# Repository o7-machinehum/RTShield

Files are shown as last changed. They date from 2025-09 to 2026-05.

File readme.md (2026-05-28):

# RPI RTShield
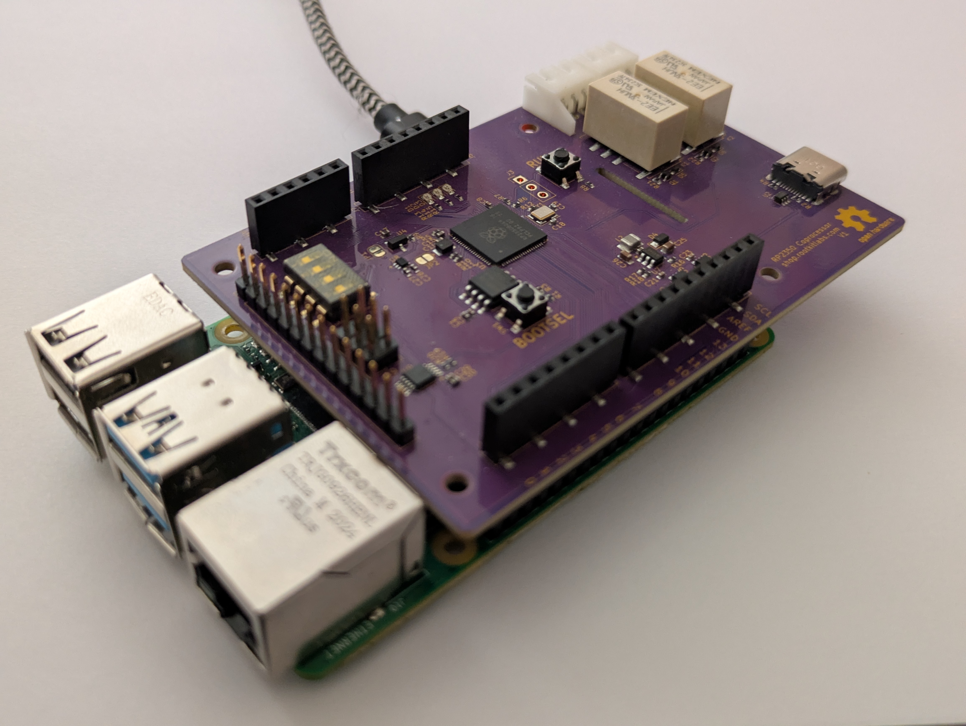
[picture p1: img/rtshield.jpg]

The RTSheild is a Raspberry PI hat containing an MCU to serve as a "realtime" companion. The PI is connected to the RP2350 over a UART link, and all sensors are wired into the RP2350 itself. The RP2350 is connected to Arduino compatible headers

## IOs
- 4x Analog output (0-3.3V, 12bit)
- 8x Analog input (0-3.3V, 12bit)
- IO's (3.3V)
- 2x Relays, for dry contacts
- Switches, for config
- LEDs

## Installing
``` bash
git clone https://github.com/o7-machinehum/RTShield
cd RTShield
git submodule update --init --recursive

sudo apt update
sudo apt install -y build-essential cmake ninja-build gcc-arm-none-eabi \
    libnewlib-arm-none-eabi python3-dev python3-pybind11 openocd

sudo raspi-config nonint do_serial_cons 1
sudo raspi-config nonint do_serial_hw 0
sudo usermod -aG dialout "$USER"

make
make flash # This flashes the RP2350

make install

# Reboot once so the serial-console setting and dialout group membership apply.
sudo reboot
```

## Running
The Python API talks to the shield over `/dev/serial0`:

``` python
import rtshield

s = rtshield.Shield("/dev/serial0")
print(s.read_analog_raw(0))
s.write_analog_voltage(0, 1.25)
s.write_digital(2, True)
s.set_led(0, True)
s.set_relay(0, True)
print(s.read_switch(0))
```

## MCU <-> RPI Coms
It's worth mentioning the UART between the MCU and the RPI isn't done very nicely right now. This is to keep things simple. I will eventually do a proper cobs encoding scheme and make things nicer.

## License
The project is licensed under the Creative Commons (4.0 International License) Attribution—Noncommercial—Share Alike license. This allows sharing and adapting material for non-commercial purposes, provided credit is given to the creator and adaptations are shared under the same terms. The material can be used in any format with necessary technical modifications, but no warranties are provided. The license prohibits imposing additional restrictions and ensures the rights are irrevocable as long as the terms are followed.

Basically... If you make boards for yourself: great, make boards for your friends: great, but **please do not sell hundreds on them on Aliexpress**.

Files in `docs/` 3rd party reference material are not covered by this licence.

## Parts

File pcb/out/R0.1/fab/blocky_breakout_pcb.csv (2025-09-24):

Reference | Value | Footprint | MPN
R7 | 0R | Resistor_SMD:R_0402_1005Metric | RC0402FR-070RL
C18,C19 | 15pF | Capacitor_SMD:C_0402_1005Metric | GJM1555C1H150GB01D
C2,C3,C4,C5,C7,C8,C9,C10,C11,C12,C13,C20,C21,C22,C23,C29 | 100nF | Capacitor_SMD:C_0402_1005Metric | CL05B104KP5NNNC
C1,C24,C27,C28 | 1uF | Capacitor_SMD:C_0402_1005Metric | JMK105BJ105KV-F
L2 | 2.2uH | Inductor_SMD:L_1008_2520Metric | DFE252012P-2R2M=P2
C6,C14,C15,C16,C17,C30 | 4.7uF | Capacitor_SMD:C_0402_1005Metric | JMK105BBJ475MV-F
C25,C26 | 10uF | Capacitor_SMD:C_0603_1608Metric | GRM188R61E106KA73J
R5,R10,R11 | 27R | Resistor_SMD:R_0402_1005Metric | RC0402FR-1327RL
R3,R6,R8,R9,R12,R13,R14,R15,R19,R20,R21,R22 | 1k | Resistor_SMD:R_0402_1005Metric | RC0402FR-131KL
R2,R4 | 5.6k | Resistor_SMD:R_0402_1005Metric | RC0402FR-135K6L
R1 | 10k | Resistor_SMD:R_0402_1005Metric | RC0402FR-1310KL
R18 | 15.8k | Resistor_SMD:R_0402_1005Metric | RC0402FR-1315K8L
R17 | 49.9k | Resistor_SMD:R_0402_1005Metric | RC0402FR-1349K9L
R16 | 100k | Resistor_SMD:R_0402_1005Metric | RC0402FR-13100KL
Y1 | 12Mhz | X_Abracon:Crystal_SMD_Abracon_ABM8-272-T3-4Pin_3.2x2.5mm | ABM8-272-T3
L1 | 3u3 | L_Abracon:AOTA-B201610S3R3-101-T | AOTA-B201610S3R3-101-T
U7 | AOZ1280CI | Package_TO_SOT_SMD:SOT-23-6 | AOZ1280CI
D5,D6 | BAT54XV2T1G | Diode_SMD:D_SOD-523 | BAT54XV2T1G
J10,J11 | Conn_01x03_Pin | Connector_JST:JST_XH_S3B-XH-A-1_1x03_P2.50mm_Horizontal | S3B-XH-A-1
J7 | Conn_01x06_Pin | Connector_PinSocket_2.54mm:PinSocket_1x06_P2.54mm_Vertical_SMD_Pin1Left | NPTC061KFXC-RC
J5,J8 | Conn_01x08_Pin | Connector_PinSocket_2.54mm:PinSocket_1x08_P2.54mm_Vertical_SMD_Pin1Left | NPTC081KFXC-RC
J6 | Conn_01x10_Pin | Connector_PinSocket_2.54mm:PinSocket_1x10_P2.54mm_Vertical_SMD_Pin1Left | NPTC101KFXC-RC
J2 | Conn_01x14_Pin | Connector_PinHeader_2.54mm:PinHeader_1x14_P2.54mm_Vertical | 77311-101-14LF
J9 | Conn_02x03_Odd_Even | Connector_PinHeader_2.54mm:PinHeader_2x03_P2.54mm_Vertical | 67997-206HLF
Q1,Q2 | DMG1012TQ-7 | Package_TO_SOT_SMD:SOT-523 | DMG1012TQ-7
K1,K4 | EE2-3NUH | Relay_SMD:Relay_DPDT_Kemet_EE2_NUH
D2 | Green | LED_SMD:LED_0603_1608Metric | LTST-C190GKT
U5,U6 | LM66100DCK | Package_TO_SOT_SMD:SOT-363_SC-70-6 | LM66100DCKR
U4 | LM4040C33FTA | Package_TO_SOT_SMD:SOT-23 | LM4040C33FTA
U9 | MCP4728 | Package_SO:MSOP-10_3x3mm_P0.5mm | MCP4728T-E/UN
D4 | MSS2P3 | Diode_SMD:D_MicroSMP_AK | MSS2P3-M3/89A
U2 | NUP2202 | Package_TO_SOT_SMD:SOT-363_SC-70-6 | NUP2202W1T2G
J4 | Raspberry_Pi_4 | Connector_PinSocket_2.54mm:PinSocket_2x20_P2.54mm_Vertical_SMD | NPTC202KFMS-RC
D1 | Red | LED_SMD:LED_0603_1608Metric | LTST-C190KRKT
U3 | RP2350 | Package_DFN_QFN:QFN-80-1EP_10x10mm_P0.4mm_EP3.4x3.4mm | RP2350B
SW3 | SW_DIP_x04 | Button_Switch_SMD:SW_DIP_SPSTx04_Slide_Omron_A6S-410x_W8.9mm_P2.54mm | A6S-4102-PH
SW1,SW2 | SW_Push | Button_Switch_SMD:SW_SPST_PTS647_Sx38 | PTS647SK38SMTR2 LFS
U8 | TCR2EE11 | Package_TO_SOT_SMD:SOT-553 | TCR2EE11,LM(CT
J1 | USB_C_Receptacle_USB2.0_16P | Connector_USB:USB_C_Receptacle_GCT_USB4105-xx-A_16P_TopMnt_Horizontal | USB4105-GF-A-120
U1 | W25Q32JVSS | Package_SO:SOIC-8_5.3x5.3mm_P1.27mm | W25Q32JVSSIQ
D3 | Yellow | LED_SMD:LED_0603_1608Metric | LTST-C190KSKT

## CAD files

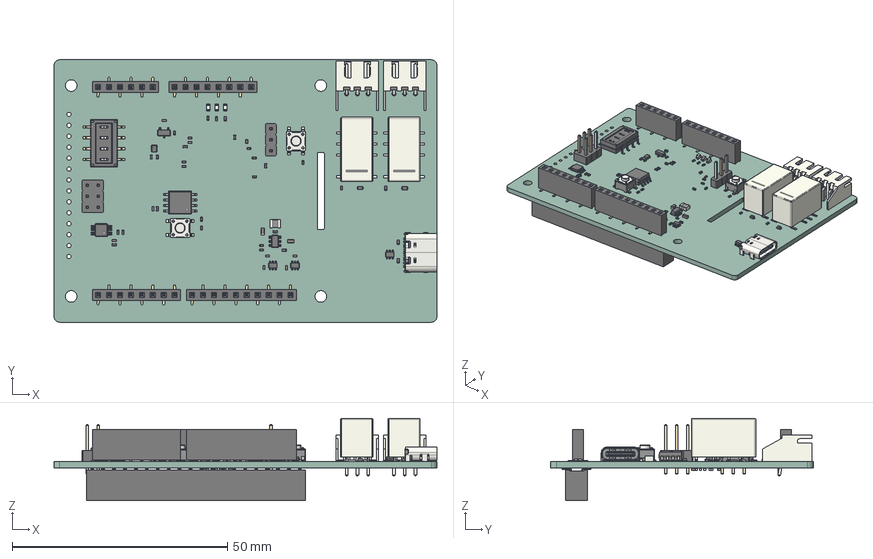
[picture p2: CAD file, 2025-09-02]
pcb/out/R0.1/blocky_breakout_pcb.step
89.0 x 61.0 x 19.2 mm
C_0402_1005Metric x 28
R_0402_1005Metric x 22
SOIC-8_5.3x5.3mm_P1.27mm
SW_SPST_PTS647Sx38 x 2
SOT-363_SC-70-6 x 3
D_SOD-523 x 2
PinHeader_2x03_P2.54mm_Vertical
Relay_DPDT_Kemet_EE2_NU x 2
LED_0603_1608Metric x 3
PinSocket_1x08_P2.54mm_Vertical_SMD_Pin1Left x 2
SOT-553
SOT-23
L_1008_2520Metric
USB_C_Receptacle_GCT_USB4105-xx-A_16P_TopMnt_Horizontal
PinHeader_1x03_P2.54mm_Vertical
JST_XH_S3B-XH-A-1_1x03_P2.50mm_Horizontal x 2
SOT-23-6
PinSocket_1x06_P2.54mm_Vertical_SMD_Pin1Left
C_0603_1608Metric x 2
SW_DIP_SPSTx04_Slide_Omron_A6S-410x_W8.9mm_P2.54mm
MSOP-10_3x3mm_P0.5mm
PinSocket_1x10_P2.54mm_Vertical_SMD_Pin1Left
PinSocket_2x20_P2.54mm_Vertical_SMD
blocky_breakout_pcb_PCB

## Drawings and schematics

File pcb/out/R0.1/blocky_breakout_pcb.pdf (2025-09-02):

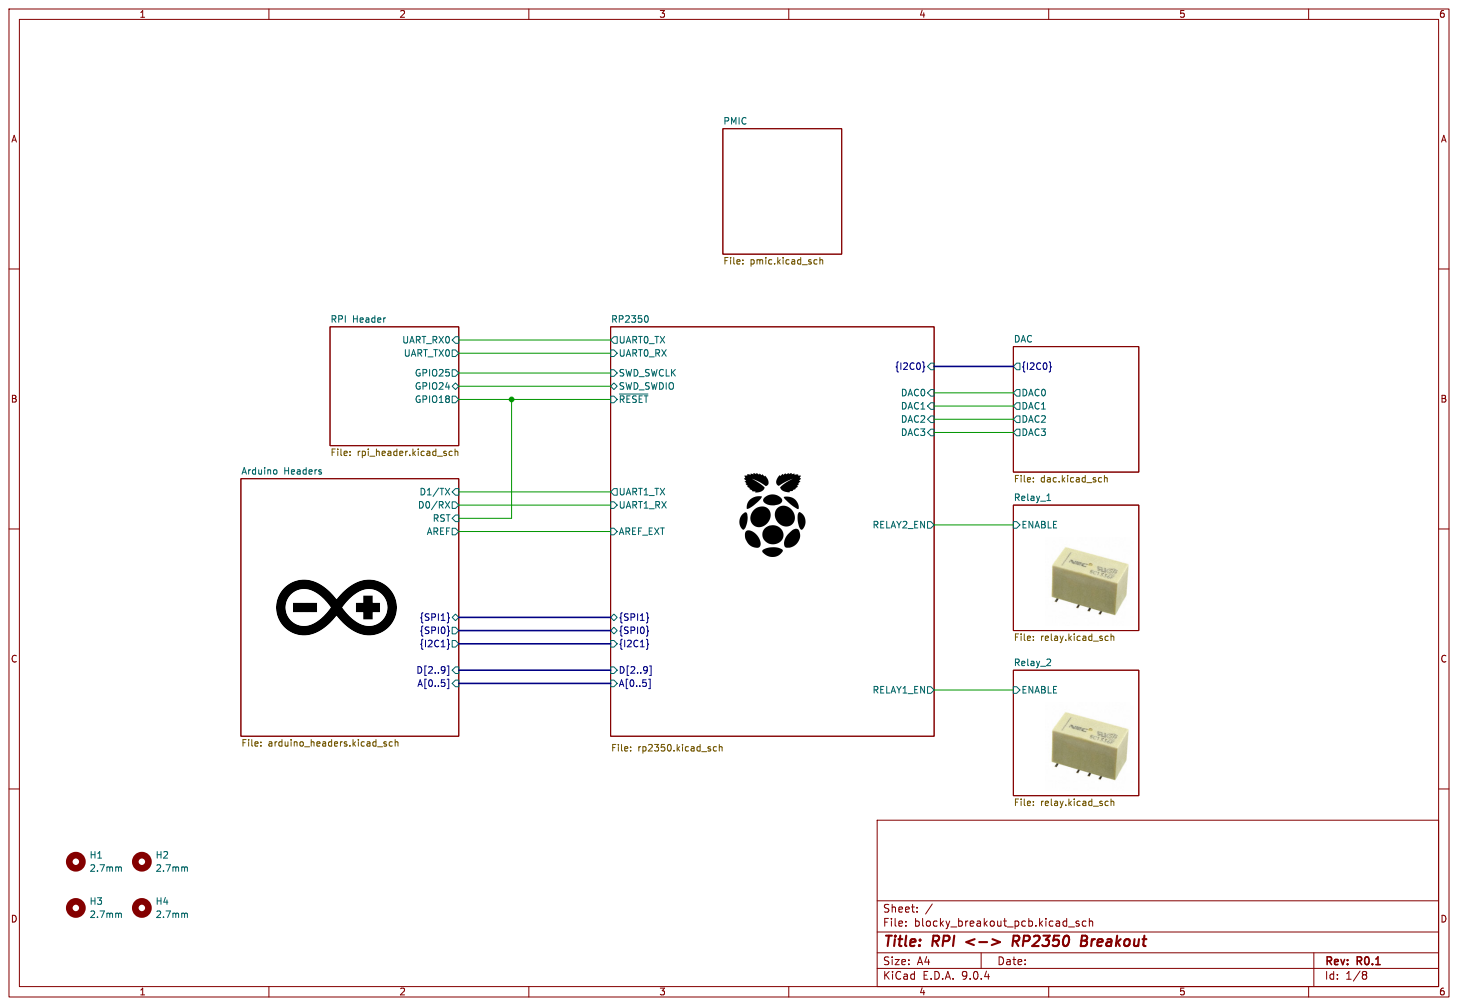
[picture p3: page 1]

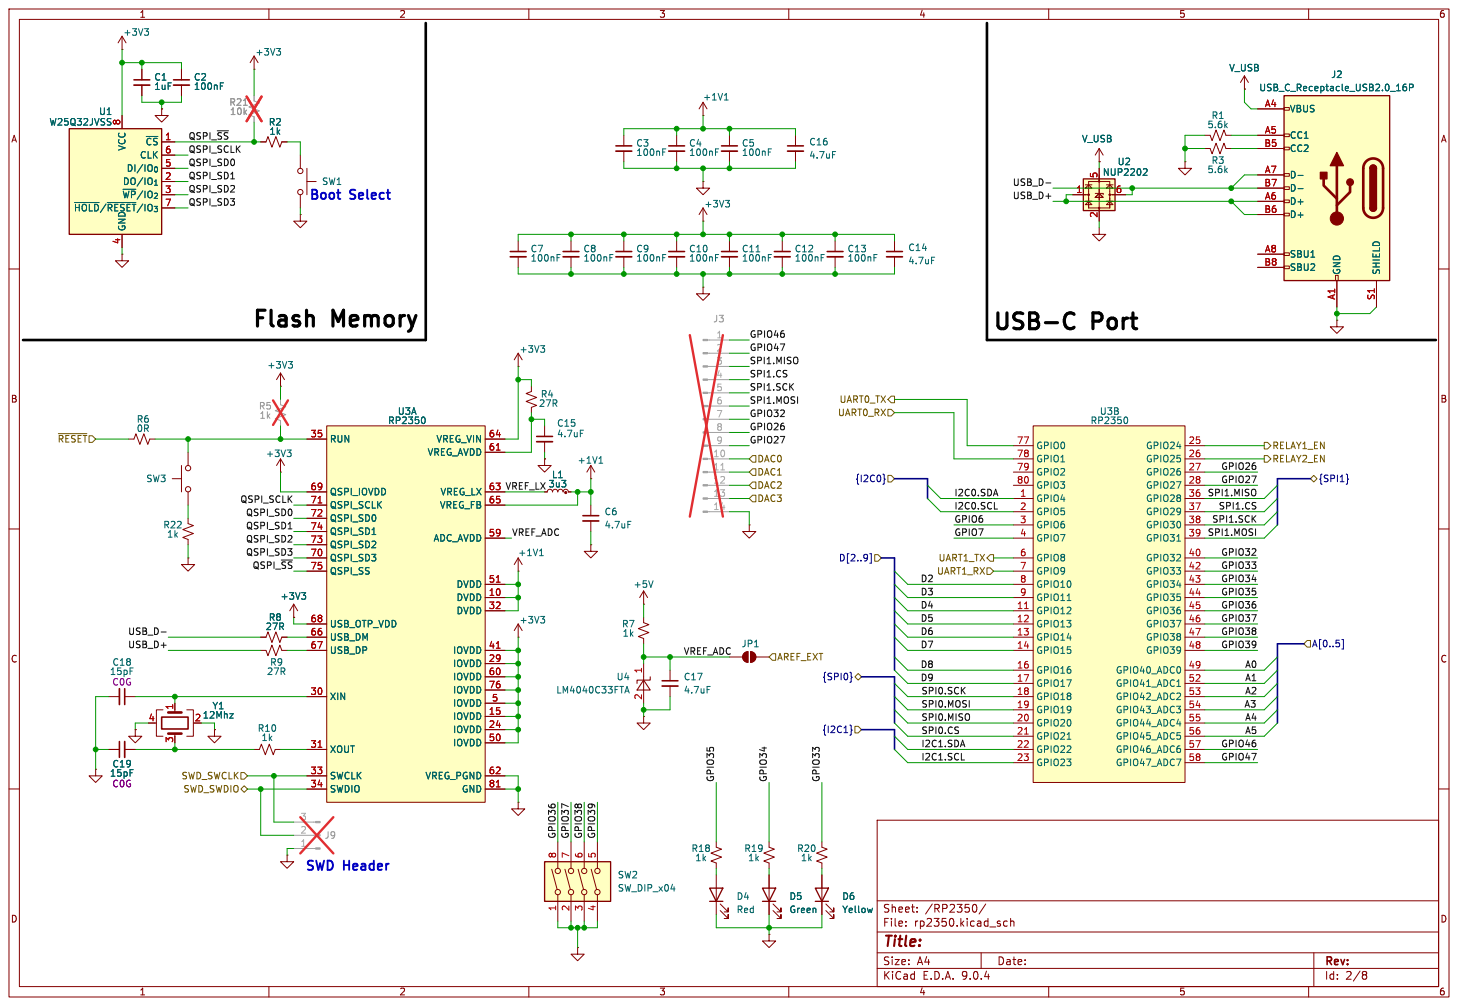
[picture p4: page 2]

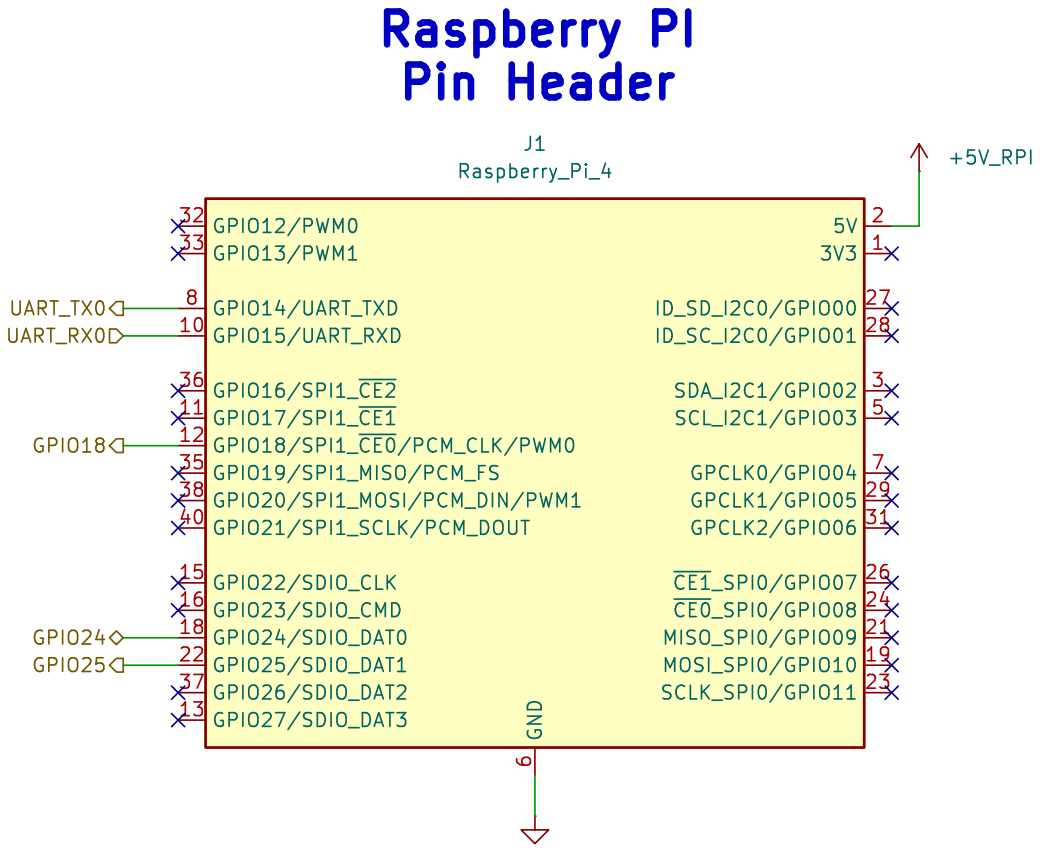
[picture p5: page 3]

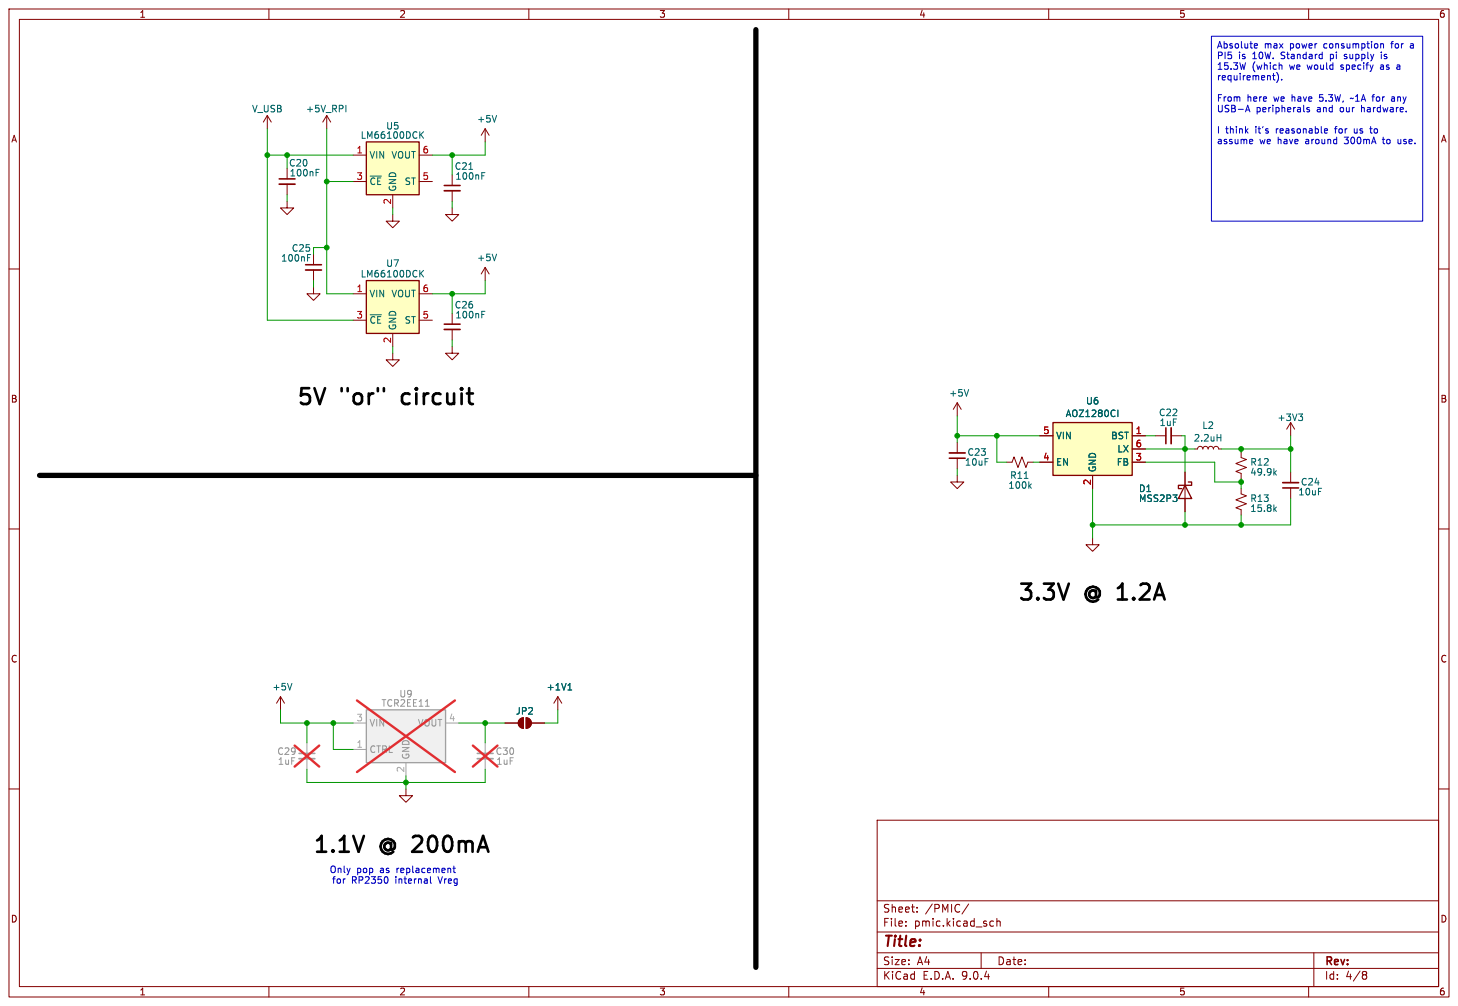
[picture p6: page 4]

assume we have around 300mA to use. 1.1V @ 200mA

Only pop as replacement

Id: 4/8 Title: File: pmic.kicad_sch Sheet: /PMIC/

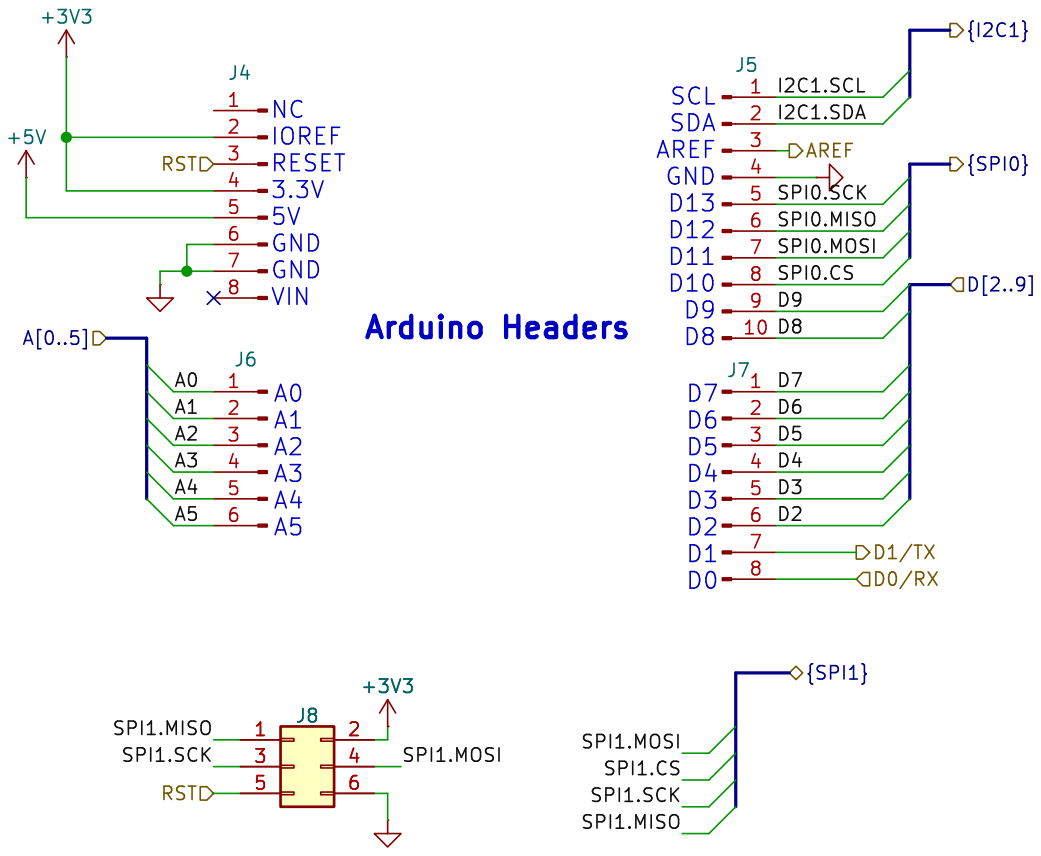
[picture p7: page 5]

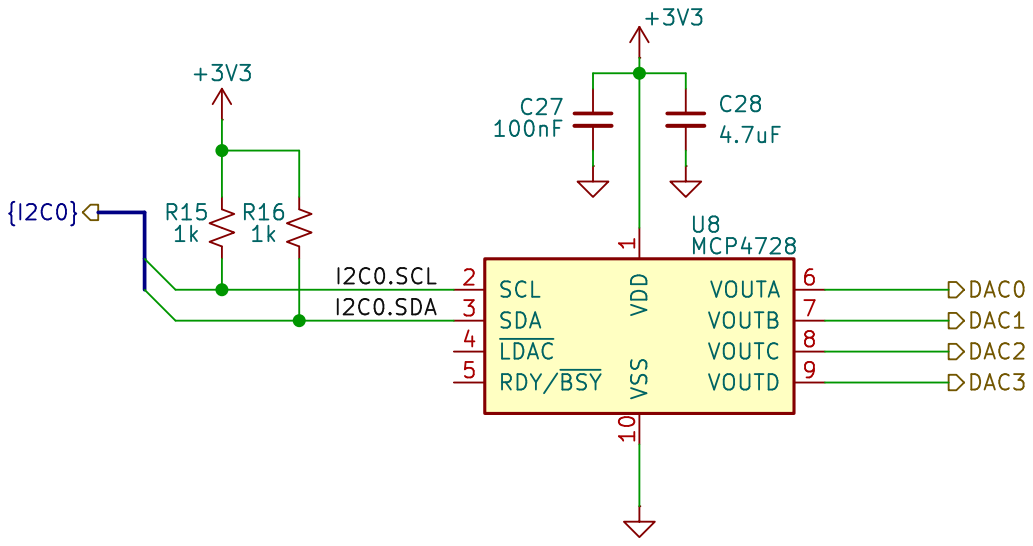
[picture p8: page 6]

1 VSS 10 VOUTA 6 VOUTB 7 VOUTC 8 VOUTD 9 U8 MCP4728 R15

Id: 6/8 Title: File: dac.kicad_sch Sheet: /DAC/

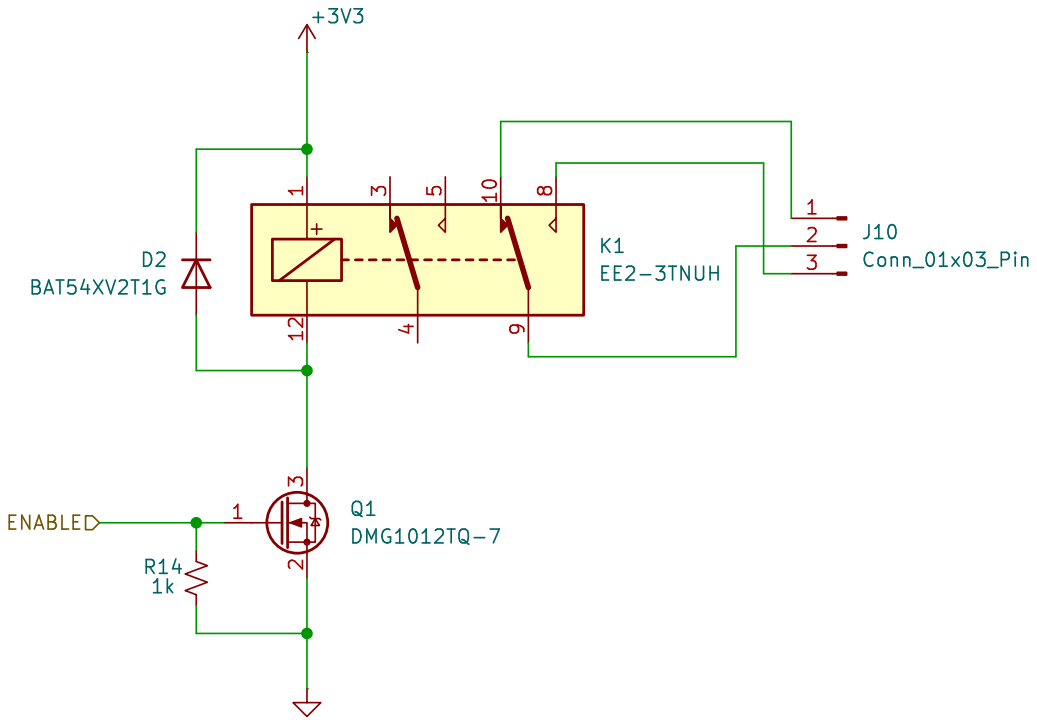
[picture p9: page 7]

Id: 7/8 Title: File: relay.kicad_sch Sheet: /Relay_1/

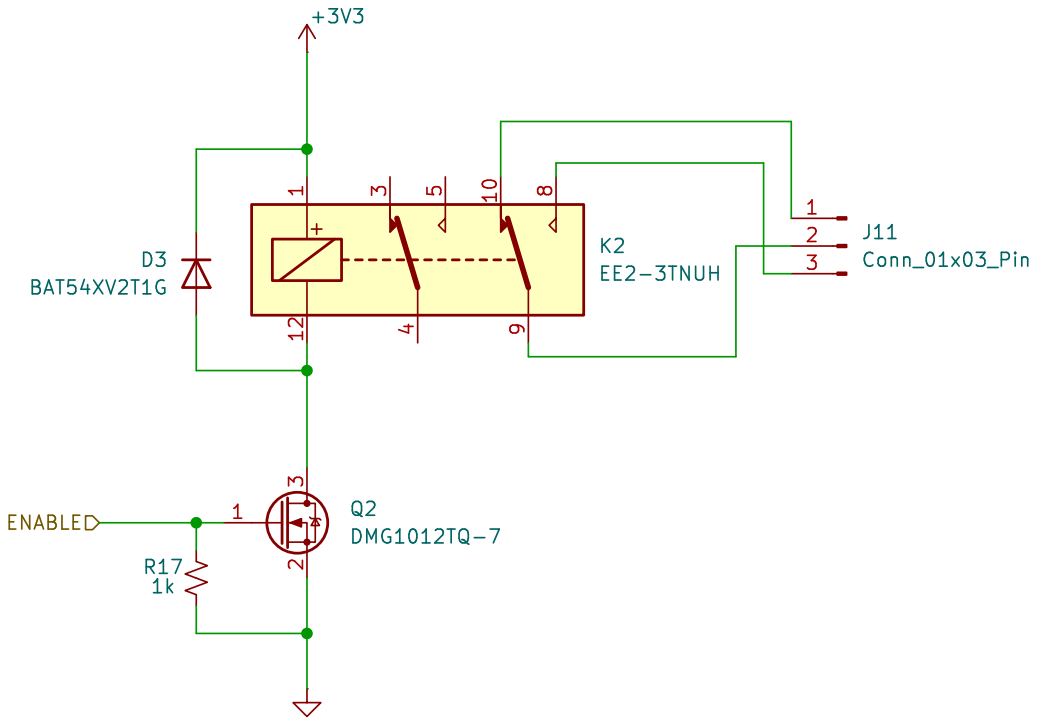
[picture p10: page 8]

Id: 8/8 Title: File: relay.kicad_sch Sheet: /Relay_2/

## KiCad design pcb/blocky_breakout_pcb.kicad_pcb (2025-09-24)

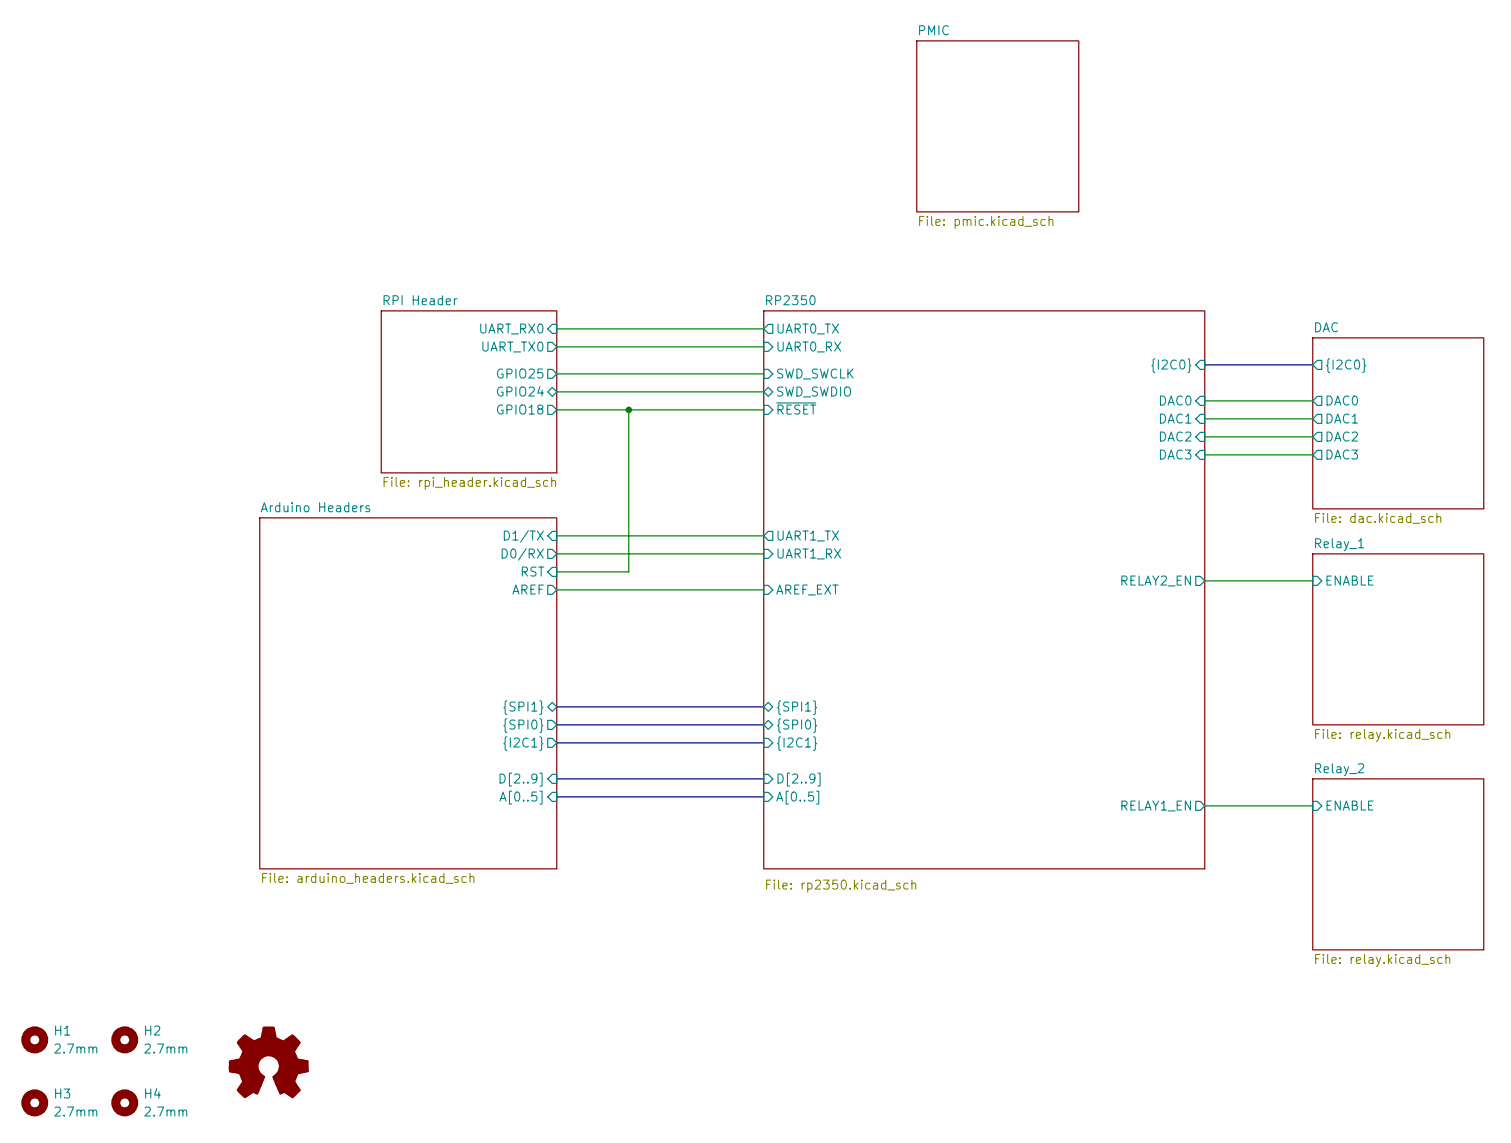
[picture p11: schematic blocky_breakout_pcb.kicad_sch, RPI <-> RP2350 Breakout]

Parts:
H1, H2, H3, H4: 2.7mm; MountingHole_2.7mm_M2.5

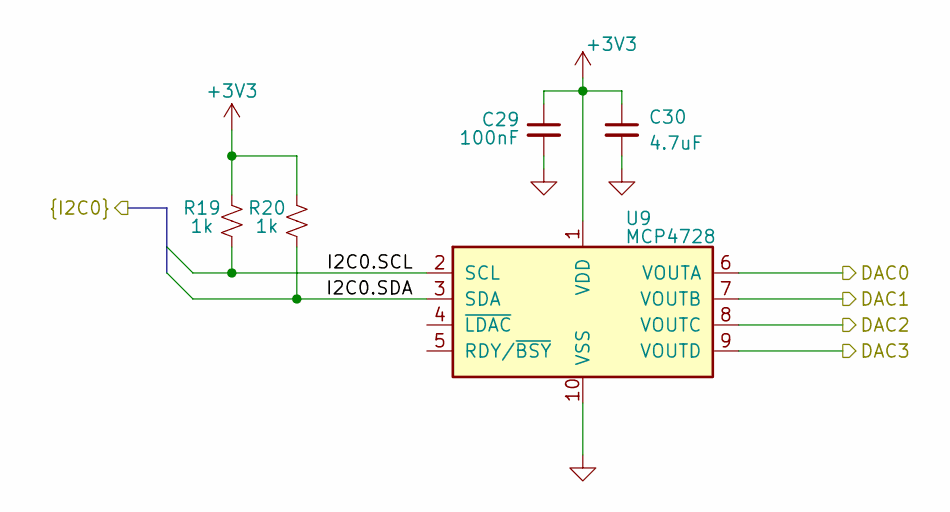
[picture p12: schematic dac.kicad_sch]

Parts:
C29: 100nF; C_0402_1005Metric; MPN CL05B104KP5NNNC
C30: 4.7uF; C_0402_1005Metric; MPN JMK105BBJ475MV-F
R19, R20: 1k; R_0402_1005Metric; MPN RC0402FR-131KL
U9: MCP4728; MSOP-10_3x3mm_P0.5mm; MPN MCP4728T-E/UN

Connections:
+3V3: C29.1, C30.1, R19.2, R20.2, U9.1 (VDD); also elsewhere on the board
/DAC/DAC0: U9.6 (VOUTA); also elsewhere on the board
/DAC/DAC1: U9.7 (VOUTB); also elsewhere on the board
/DAC/DAC2: U9.8 (VOUTC); also elsewhere on the board
/DAC/DAC3: U9.9 (VOUTD); also elsewhere on the board
/DAC/I2C0.SCL: R19.1, U9.2 (SCL); also elsewhere on the board
/DAC/I2C0.SDA: R20.1, U9.3 (SDA); also elsewhere on the board
GND: C29.2, C30.2, U9.10 (VSS); also elsewhere on the board

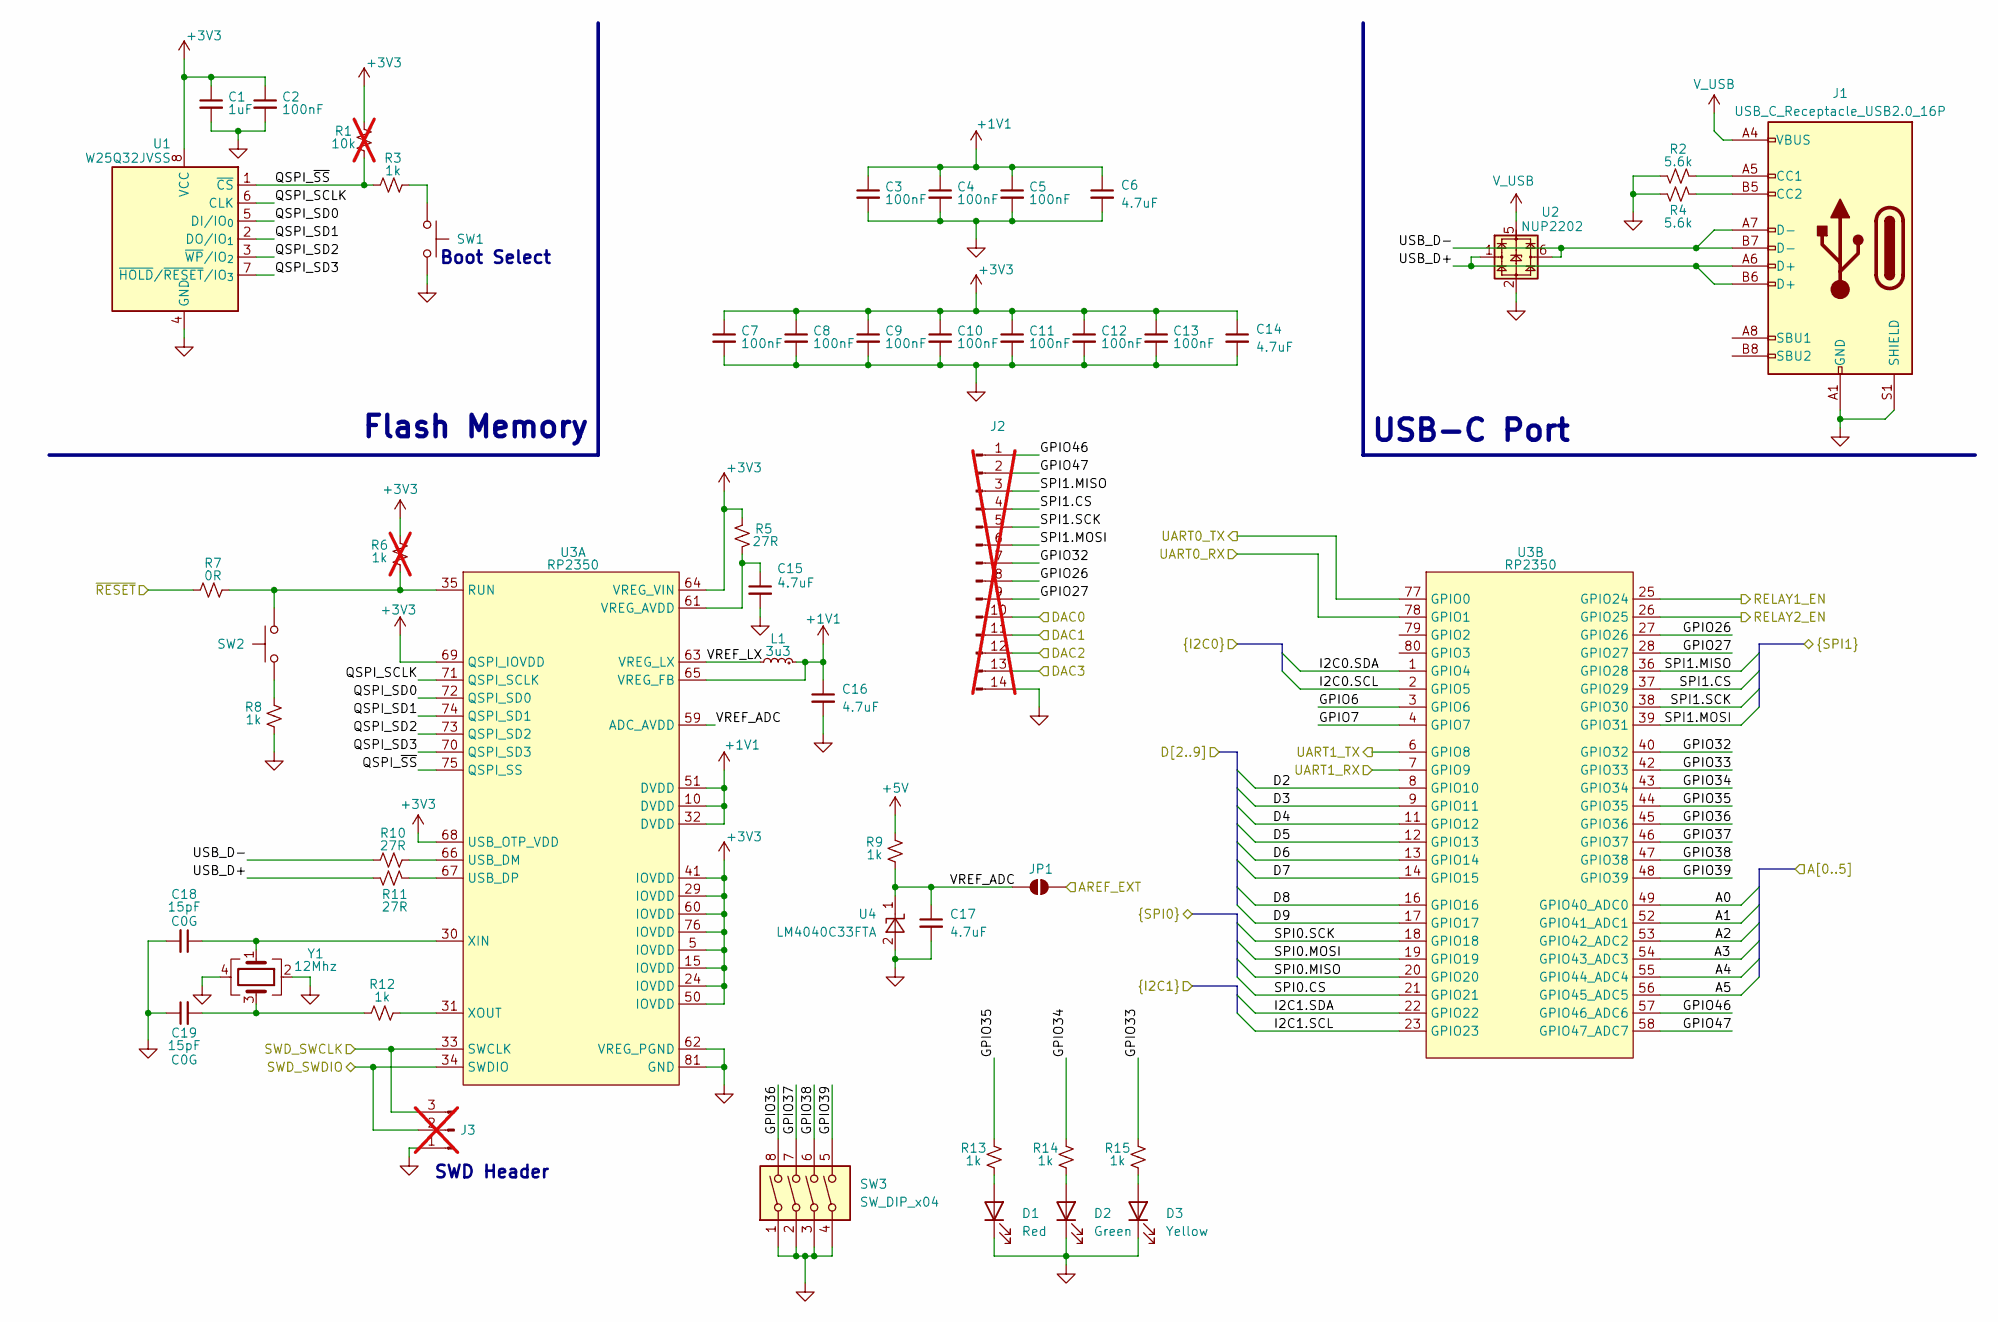
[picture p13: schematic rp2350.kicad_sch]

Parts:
C1: 1uF; C_0402_1005Metric; MPN JMK105BJ105KV-F
C2, C3, C4, C5, C7, C8, C9, C10, C11, C12, C13: 100nF; C_0402_1005Metric; MPN CL05B104KP5NNNC
C6, C14, C15, C16, C17: 4.7uF; C_0402_1005Metric; MPN JMK105BBJ475MV-F
C18, C19: 15pF; C_0402_1005Metric; MPN GJM1555C1H150GB01D
D1: Red; LED_0603_1608Metric; MPN LTST-C190KRKT
D2: Green; LED_0603_1608Metric; MPN LTST-C190GKT
D3: Yellow; LED_0603_1608Metric; MPN LTST-C190KSKT
J1: USB_C_Receptacle_USB2.0_16P; USB_C_Receptacle_GCT_USB4105-xx-A_16P_TopMnt_Horizontal; MPN USB4105-GF-A-120
J2: Conn_01x14_Pin; PinHeader_1x14_P2.54mm_Vertical; MPN 77311-101-14LF; not fitted
J3: Conn_01x03_Pin; PinHeader_1x03_P2.54mm_Vertical; not fitted
JP1: SolderJumper_2_Open; SolderJumper-2_P1.3mm_Open_RoundedPad1.0x1.5mm
L1: 3u3; AOTA-B201610S3R3-101-T; MPN AOTA-B201610S3R3-101-T
R1: 10k; R_0402_1005Metric; MPN RC0402FR-1310KL; not fitted
R2, R4: 5.6k; R_0402_1005Metric; MPN RC0402FR-135K6L
R3, R8, R9, R12, R13, R14, R15: 1k; R_0402_1005Metric; MPN RC0402FR-131KL
R5, R10, R11: 27R; R_0402_1005Metric; MPN RC0402FR-1327RL
R6: 1k; R_0402_1005Metric; MPN RC0402FR-131KL; not fitted
R7: 0R; R_0402_1005Metric; MPN RC0402FR-070RL
SW1, SW2: SW_Push; SW_SPST_PTS647_Sx38; MPN PTS647SK38SMTR2 LFS
SW3: SW_DIP_x04; SW_DIP_SPSTx04_Slide_Omron_A6S-410x_W8.9mm_P2.54mm; MPN A6S-4102-PH
U1: W25Q32JVSS; SOIC-8_5.3x5.3mm_P1.27mm; MPN W25Q32JVSSIQ
U2: NUP2202; SOT-363_SC-70-6; MPN NUP2202W1T2G
U3: RP2350; QFN-80-1EP_10x10mm_P0.4mm_EP3.4x3.4mm; MPN RP2350B
U4: LM4040C33FTA; SOT-23; MPN LM4040C33FTA
Y1: 12Mhz; Crystal_SMD_Abracon_ABM8-272-T3-4Pin_3.2x2.5mm; MPN ABM8-272-T3

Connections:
+1V1: C3.1, C4.1, C5.1, C6.1, C16.1, L1.1, U3.10 (DVDD), U3.32 (DVDD), U3.51 (DVDD), U3.65 (VREG_FB); also elsewhere on the board
+3V3: C1.1, C2.1, C7.1, C8.1, C9.1, C10.1, C11.1, C12.1, C13.1, C14.1, R1.2, R5.2, R6.2, U1.8 (VCC), U3.5 (IOVDD), U3.15 (IOVDD), U3.24 (IOVDD), U3.29 (IOVDD), U3.41 (IOVDD), U3.50 (IOVDD), U3.60 (IOVDD), U3.64 (VREG_VIN), U3.68 (USB_OTP_VDD), U3.69 (QSPI_IOVDD), U3.76 (IOVDD); also elsewhere on the board
+5V: R9.2; also elsewhere on the board
/Arduino Headers/A0: U3.49 (GPIO40_ADC0); also elsewhere on the board
/Arduino Headers/A1: U3.52 (GPIO41_ADC1); also elsewhere on the board
/Arduino Headers/A2: U3.53 (GPIO42_ADC2); also elsewhere on the board
/Arduino Headers/A3: U3.54 (GPIO43_ADC3); also elsewhere on the board
/Arduino Headers/A4: U3.55 (GPIO44_ADC4); also elsewhere on the board
/Arduino Headers/A5: U3.56 (GPIO45_ADC5); also elsewhere on the board
/Arduino Headers/AREF: JP1.2 (B); also elsewhere on the board
/Arduino Headers/D0/RX: U3.7 (GPIO9); also elsewhere on the board
/Arduino Headers/D1/TX: U3.6 (GPIO8); also elsewhere on the board
/Arduino Headers/D2: U3.8 (GPIO10); also elsewhere on the board
/Arduino Headers/D3: U3.9 (GPIO11); also elsewhere on the board
/Arduino Headers/D4: U3.11 (GPIO12); also elsewhere on the board
/Arduino Headers/D5: U3.12 (GPIO13); also elsewhere on the board
/Arduino Headers/D6: U3.13 (GPIO14); also elsewhere on the board
/Arduino Headers/D7: U3.14 (GPIO15); also elsewhere on the board
/Arduino Headers/D8: U3.16 (GPIO16); also elsewhere on the board
/Arduino Headers/D9: U3.17 (GPIO17); also elsewhere on the board
/Arduino Headers/I2C1.SCL: U3.23 (GPIO23); also elsewhere on the board
/Arduino Headers/I2C1.SDA: U3.22 (GPIO22); also elsewhere on the board
/Arduino Headers/RST: R7.1; also elsewhere on the board
/Arduino Headers/SPI0.CS: U3.21 (GPIO21); also elsewhere on the board
/Arduino Headers/SPI0.MISO: U3.20 (GPIO20); also elsewhere on the board
/Arduino Headers/SPI0.MOSI: U3.19 (GPIO19); also elsewhere on the board
/Arduino Headers/SPI0.SCK: U3.18 (GPIO18); also elsewhere on the board
/Arduino Headers/SPI1.CS: J2.4, U3.37 (GPIO29)
/Arduino Headers/SPI1.MISO: J2.3, U3.36 (GPIO28); also elsewhere on the board
/Arduino Headers/SPI1.MOSI: J2.6, U3.39 (GPIO31); also elsewhere on the board
/Arduino Headers/SPI1.SCK: J2.5, U3.38 (GPIO30); also elsewhere on the board
/DAC/DAC0: J2.10; also elsewhere on the board
/DAC/DAC1: J2.11; also elsewhere on the board
/DAC/DAC2: J2.12; also elsewhere on the board
/DAC/DAC3: J2.13; also elsewhere on the board
/DAC/I2C0.SCL: U3.2 (GPIO5); also elsewhere on the board
/DAC/I2C0.SDA: U3.1 (GPIO4); also elsewhere on the board
/RP2350/GPIO6: U3.3 (GPIO6)
/RP2350/GPIO7: U3.4 (GPIO7)
/RP2350/GPIO26: J2.8, U3.27 (GPIO26)
/RP2350/GPIO27: J2.9, U3.28 (GPIO27)
/RP2350/GPIO32: J2.7, U3.40 (GPIO32)
/RP2350/GPIO33: R15.2, U3.42 (GPIO33)
/RP2350/GPIO34: R14.2, U3.43 (GPIO34)
/RP2350/GPIO35: R13.2, U3.44 (GPIO35)
/RP2350/GPIO36: SW3.8, U3.45 (GPIO36)
/RP2350/GPIO37: SW3.7, U3.46 (GPIO37)
/RP2350/GPIO38: SW3.6, U3.47 (GPIO38)
/RP2350/GPIO39: SW3.5, U3.48 (GPIO39)
/RP2350/GPIO46: J2.1, U3.57 (GPIO46_ADC6)
/RP2350/GPIO47: J2.2, U3.58 (GPIO47_ADC7)
/RP2350/QSPI_SCLK: U1.6 (CLK), U3.71 (QSPI_SCLK)
/RP2350/QSPI_SD0: U1.5 (DI/IO_{0}), U3.72 (QSPI_SD0)
/RP2350/QSPI_SD1: U1.2 (DO/IO_{1}), U3.74 (QSPI_SD1)
/RP2350/QSPI_SD2: U1.3 (~WP/IO_{2}), U3.73 (QSPI_SD2)
/RP2350/QSPI_SD3: U1.7 (~HOLD/~RESET/IO_{3}), U3.70 (QSPI_SD3)
/RP2350/QSPI_~SS: R1.1, R3.1, U1.1 (~CS), U3.75 (QSPI_SS)
/RP2350/RELAY1_EN: U3.25 (GPIO24); also elsewhere on the board
/RP2350/RELAY2_EN: U3.26 (GPIO25); also elsewhere on the board
/RP2350/SWD_SWCLK: J3.3, U3.33 (SWCLK); also elsewhere on the board
/RP2350/SWD_SWDIO: J3.2, U3.34 (SWDIO); also elsewhere on the board
/RP2350/UART0_RX: U3.78 (GPIO1); also elsewhere on the board
/RP2350/UART0_TX: U3.77 (GPIO0); also elsewhere on the board
/RP2350/USB_D+: J1.A6 (D+), J1.B6 (D+), R11.1, U2.1
/RP2350/USB_D-: J1.A7 (D-), J1.B7 (D-), R10.1, U2.6
/RP2350/VREF_ADC: C17.1, JP1.1 (A), R9.1, U3.59 (ADC_AVDD), U4.1 (K)
/RP2350/VREF_LX: L1.2, U3.63 (VREG_LX)
GND: C1.2, C2.2, C3.2, C4.2, C5.2, C6.2, C7.2, C8.2, C9.2, C10.2, C11.2, C12.2, C13.2, C14.2, C15.2, C16.2, C17.2, C18.2, C19.1, D1.1 (K), D2.1 (K), D3.1 (K), J1.A1 (GND), J1.A12 (GND), J1.B1 (GND), J1.B12 (GND), J1.S1 (SHIELD), J2.14, J3.1, R2.2, R4.1, R8.1, SW1.2, SW3.1, SW3.2, SW3.3, SW3.4, U1.4 (GND), U2.2, U3.62 (VREG_PGND), U3.81 (GND), U4.2 (A), Y1.2, Y1.4; also elsewhere on the board
unnamed: C19.2, R12.1, Y1.3
unnamed: D1.2 (A), R13.1
unnamed: D2.2 (A), R14.1
unnamed: D3.2 (A), R15.1
unnamed: J1.A5 (CC1), R2.1
unnamed: J1.B5 (CC2), R4.2
unnamed: R3.2, SW1.1
unnamed: R8.2, SW2.1
unnamed: R6.1, R7.2, SW2.2, U3.35 (RUN)
unnamed: R10.2, U3.66 (USB_DM)
unnamed: R11.2, U3.67 (USB_DP)
unnamed: C15.1, R5.1, U3.61 (VREG_AVDD)
unnamed: C18.1, U3.30 (XIN), Y1.1
unnamed: R12.2, U3.31 (XOUT)
V_USB: J1.A4 (VBUS), J1.A9 (VBUS), J1.B4 (VBUS), J1.B9 (VBUS), U2.5; also elsewhere on the board

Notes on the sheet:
SWD Header
Flash Memory
Boot Select
USB-C Port

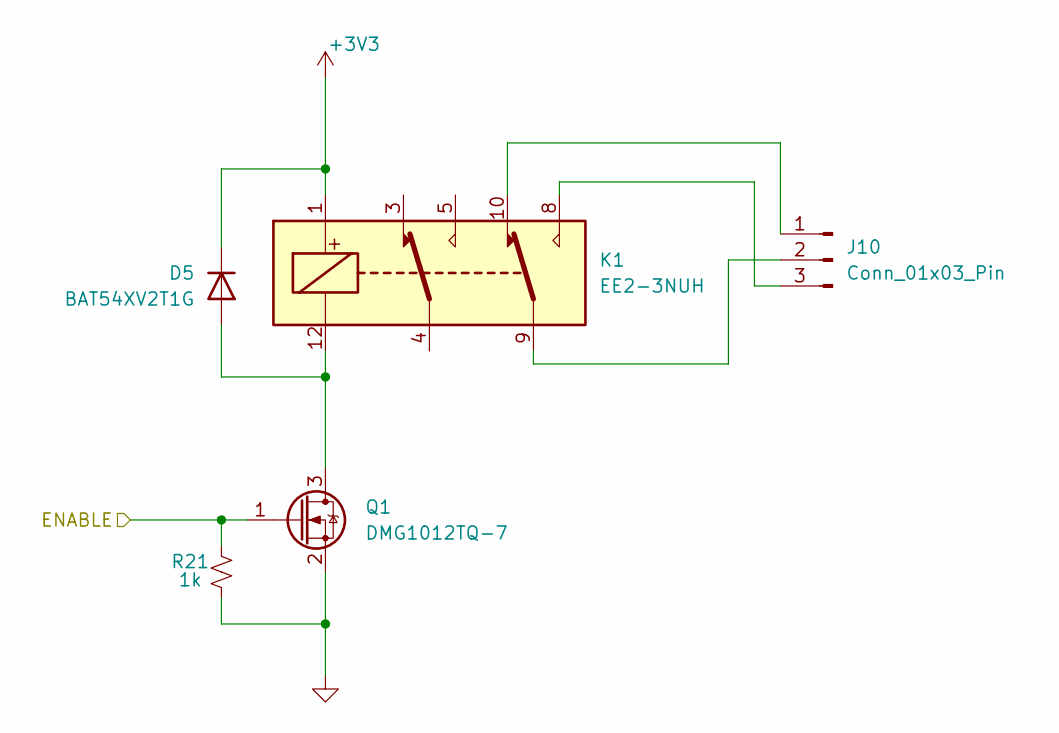
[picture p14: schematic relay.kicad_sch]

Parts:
D5: BAT54XV2T1G; D_SOD-523; MPN BAT54XV2T1G
J10: Conn_01x03_Pin; JST_XH_S3B-XH-A-1_1x03_P2.50mm_Horizontal; MPN S3B-XH-A-1
K1: EE2-3NUH; Relay_DPDT_Kemet_EE2_NUH
Q1: DMG1012TQ-7; SOT-523; MPN DMG1012TQ-7
R21: 1k; R_0402_1005Metric; MPN RC0402FR-131KL

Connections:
+3V3: D5.1 (K), K1.1; also elsewhere on the board
/RP2350/RELAY2_EN: Q1.1 (G), R21.1; also elsewhere on the board
GND: Q1.2 (S), R21.2; also elsewhere on the board
unnamed: D5.2 (A), K1.12, Q1.3 (D)
unnamed: J10.1, K1.10
unnamed: J10.2, K1.9
unnamed: J10.3, K1.8

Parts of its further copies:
D6: BAT54XV2T1G; D_SOD-523; MPN BAT54XV2T1G
J11: Conn_01x03_Pin; JST_XH_S3B-XH-A-1_1x03_P2.50mm_Horizontal; MPN S3B-XH-A-1
Q2: DMG1012TQ-7; SOT-523; MPN DMG1012TQ-7
R22: 1k; R_0402_1005Metric; MPN RC0402FR-131KL

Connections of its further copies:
+3V3: D6.1 (K); also elsewhere on the board
/RP2350/RELAY1_EN: Q2.1 (G), R22.1; also elsewhere on the board
GND: Q2.2 (S), R22.2; also elsewhere on the board
unnamed 75: D6.2 (A), Q2.3 (D); also elsewhere on the board
unnamed 81: J11.1; also elsewhere on the board
unnamed 82: J11.2; also elsewhere on the board
unnamed 83: J11.3; also elsewhere on the board

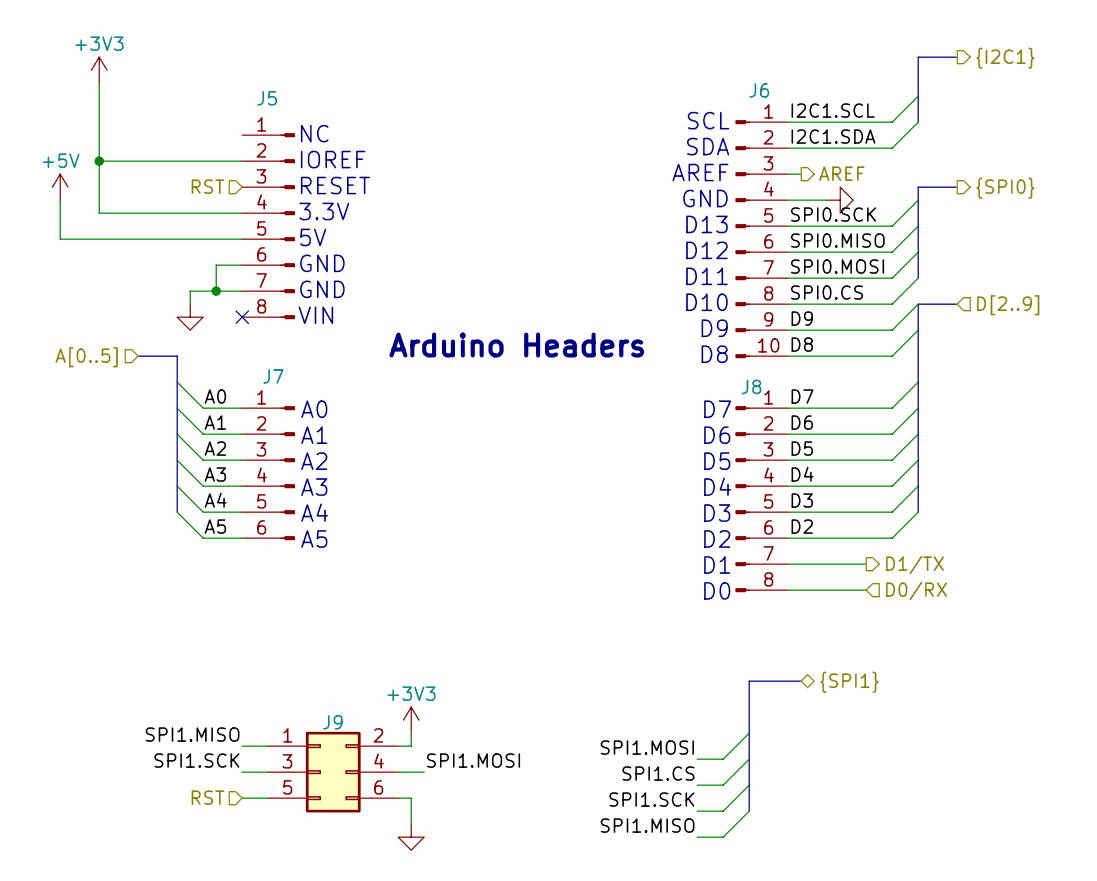
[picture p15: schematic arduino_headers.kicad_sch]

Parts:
J5, J8: Conn_01x08_Pin; PinSocket_1x08_P2.54mm_Vertical_SMD_Pin1Left; MPN NPTC081KFXC-RC
J6: Conn_01x10_Pin; PinSocket_1x10_P2.54mm_Vertical_SMD_Pin1Left; MPN NPTC101KFXC-RC
J7: Conn_01x06_Pin; PinSocket_1x06_P2.54mm_Vertical_SMD_Pin1Left; MPN NPTC061KFXC-RC
J9: Conn_02x03_Odd_Even; PinHeader_2x03_P2.54mm_Vertical; MPN 67997-206HLF

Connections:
+3V3: J5.2, J5.4, J9.2; also elsewhere on the board
+5V: J5.5; also elsewhere on the board
/Arduino Headers/A0: J7.1; also elsewhere on the board
/Arduino Headers/A1: J7.2; also elsewhere on the board
/Arduino Headers/A2: J7.3; also elsewhere on the board
/Arduino Headers/A3: J7.4; also elsewhere on the board
/Arduino Headers/A4: J7.5; also elsewhere on the board
/Arduino Headers/A5: J7.6; also elsewhere on the board
/Arduino Headers/AREF: J6.3; also elsewhere on the board
/Arduino Headers/D0/RX: J8.8; also elsewhere on the board
/Arduino Headers/D1/TX: J8.7; also elsewhere on the board
/Arduino Headers/D2: J8.6; also elsewhere on the board
/Arduino Headers/D3: J8.5; also elsewhere on the board
/Arduino Headers/D4: J8.4; also elsewhere on the board
/Arduino Headers/D5: J8.3; also elsewhere on the board
/Arduino Headers/D6: J8.2; also elsewhere on the board
/Arduino Headers/D7: J8.1; also elsewhere on the board
/Arduino Headers/D8: J6.10; also elsewhere on the board
/Arduino Headers/D9: J6.9; also elsewhere on the board
/Arduino Headers/I2C1.SCL: J6.1; also elsewhere on the board
/Arduino Headers/I2C1.SDA: J6.2; also elsewhere on the board
/Arduino Headers/RST: J5.3, J9.5; also elsewhere on the board
/Arduino Headers/SPI0.CS: J6.8; also elsewhere on the board
/Arduino Headers/SPI0.MISO: J6.6; also elsewhere on the board
/Arduino Headers/SPI0.MOSI: J6.7; also elsewhere on the board
/Arduino Headers/SPI0.SCK: J6.5; also elsewhere on the board
/Arduino Headers/SPI1.MISO: J9.1; also elsewhere on the board
/Arduino Headers/SPI1.MOSI: J9.4; also elsewhere on the board
/Arduino Headers/SPI1.SCK: J9.3; also elsewhere on the board
GND: J5.6, J5.7, J6.4, J9.6; also elsewhere on the board

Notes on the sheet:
NC IOREF RESET 3.3V 5V GND GND VIN
D7 D6 D5 D4 D3 D2 D1 D0
SCL SDA AREF GND D13 D12 D11 D10 D9 D8
Arduino Headers
A0 A1 A2 A3 A4 A5

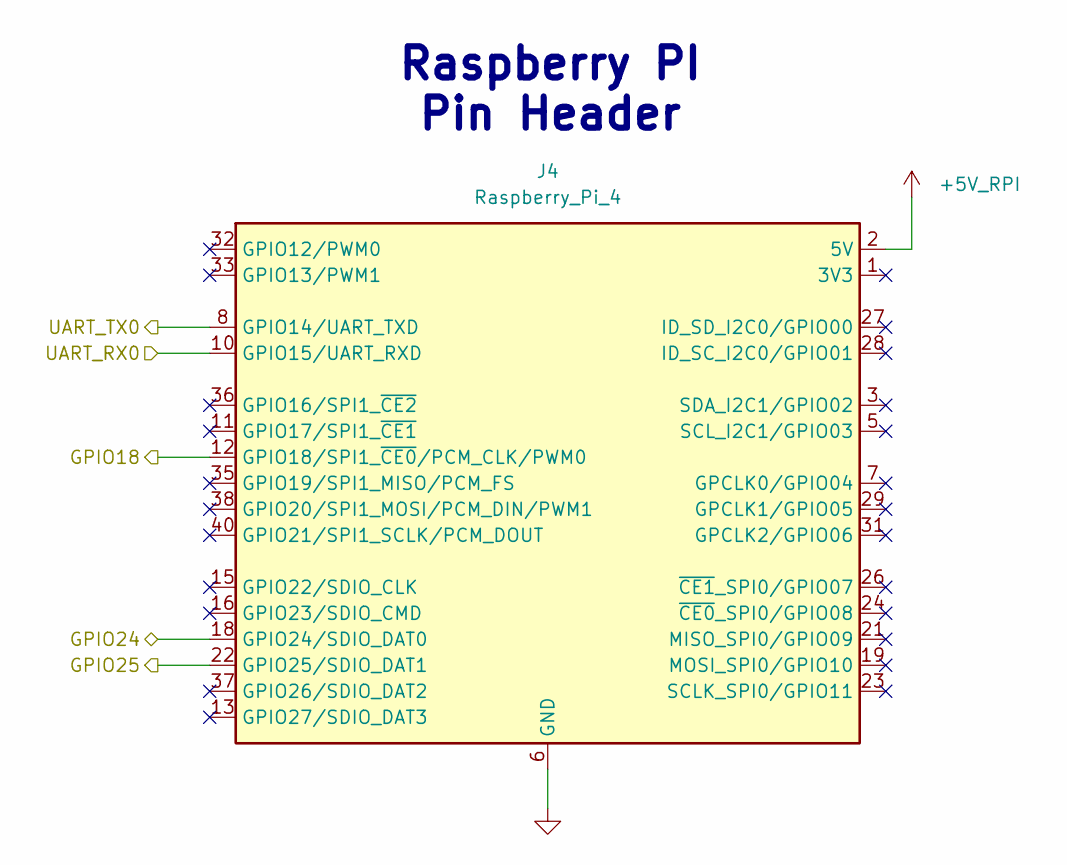
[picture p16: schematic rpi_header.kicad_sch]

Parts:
J4: Raspberry_Pi_4; PinSocket_2x20_P2.54mm_Vertical_SMD; MPN NPTC202KFMS-RC

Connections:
+5V_RPI: J4.2 (5V), J4.4 (5V); also elsewhere on the board
/Arduino Headers/RST: J4.12 (GPIO18/SPI1_~CE0/PCM_CLK/PWM0); also elsewhere on the board
/RP2350/SWD_SWCLK: J4.22 (GPIO25/SDIO_DAT1); also elsewhere on the board
/RP2350/SWD_SWDIO: J4.18 (GPIO24/SDIO_DAT0); also elsewhere on the board
/RP2350/UART0_RX: J4.8 (GPIO14/UART_TXD); also elsewhere on the board
/RP2350/UART0_TX: J4.10 (GPIO15/UART_RXD); also elsewhere on the board
GND: J4.6 (GND), J4.9 (GND), J4.14 (GND), J4.20 (GND), J4.25 (GND), J4.30 (GND), J4.34 (GND), J4.39 (GND); also elsewhere on the board

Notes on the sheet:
Raspberry PI Pin Header

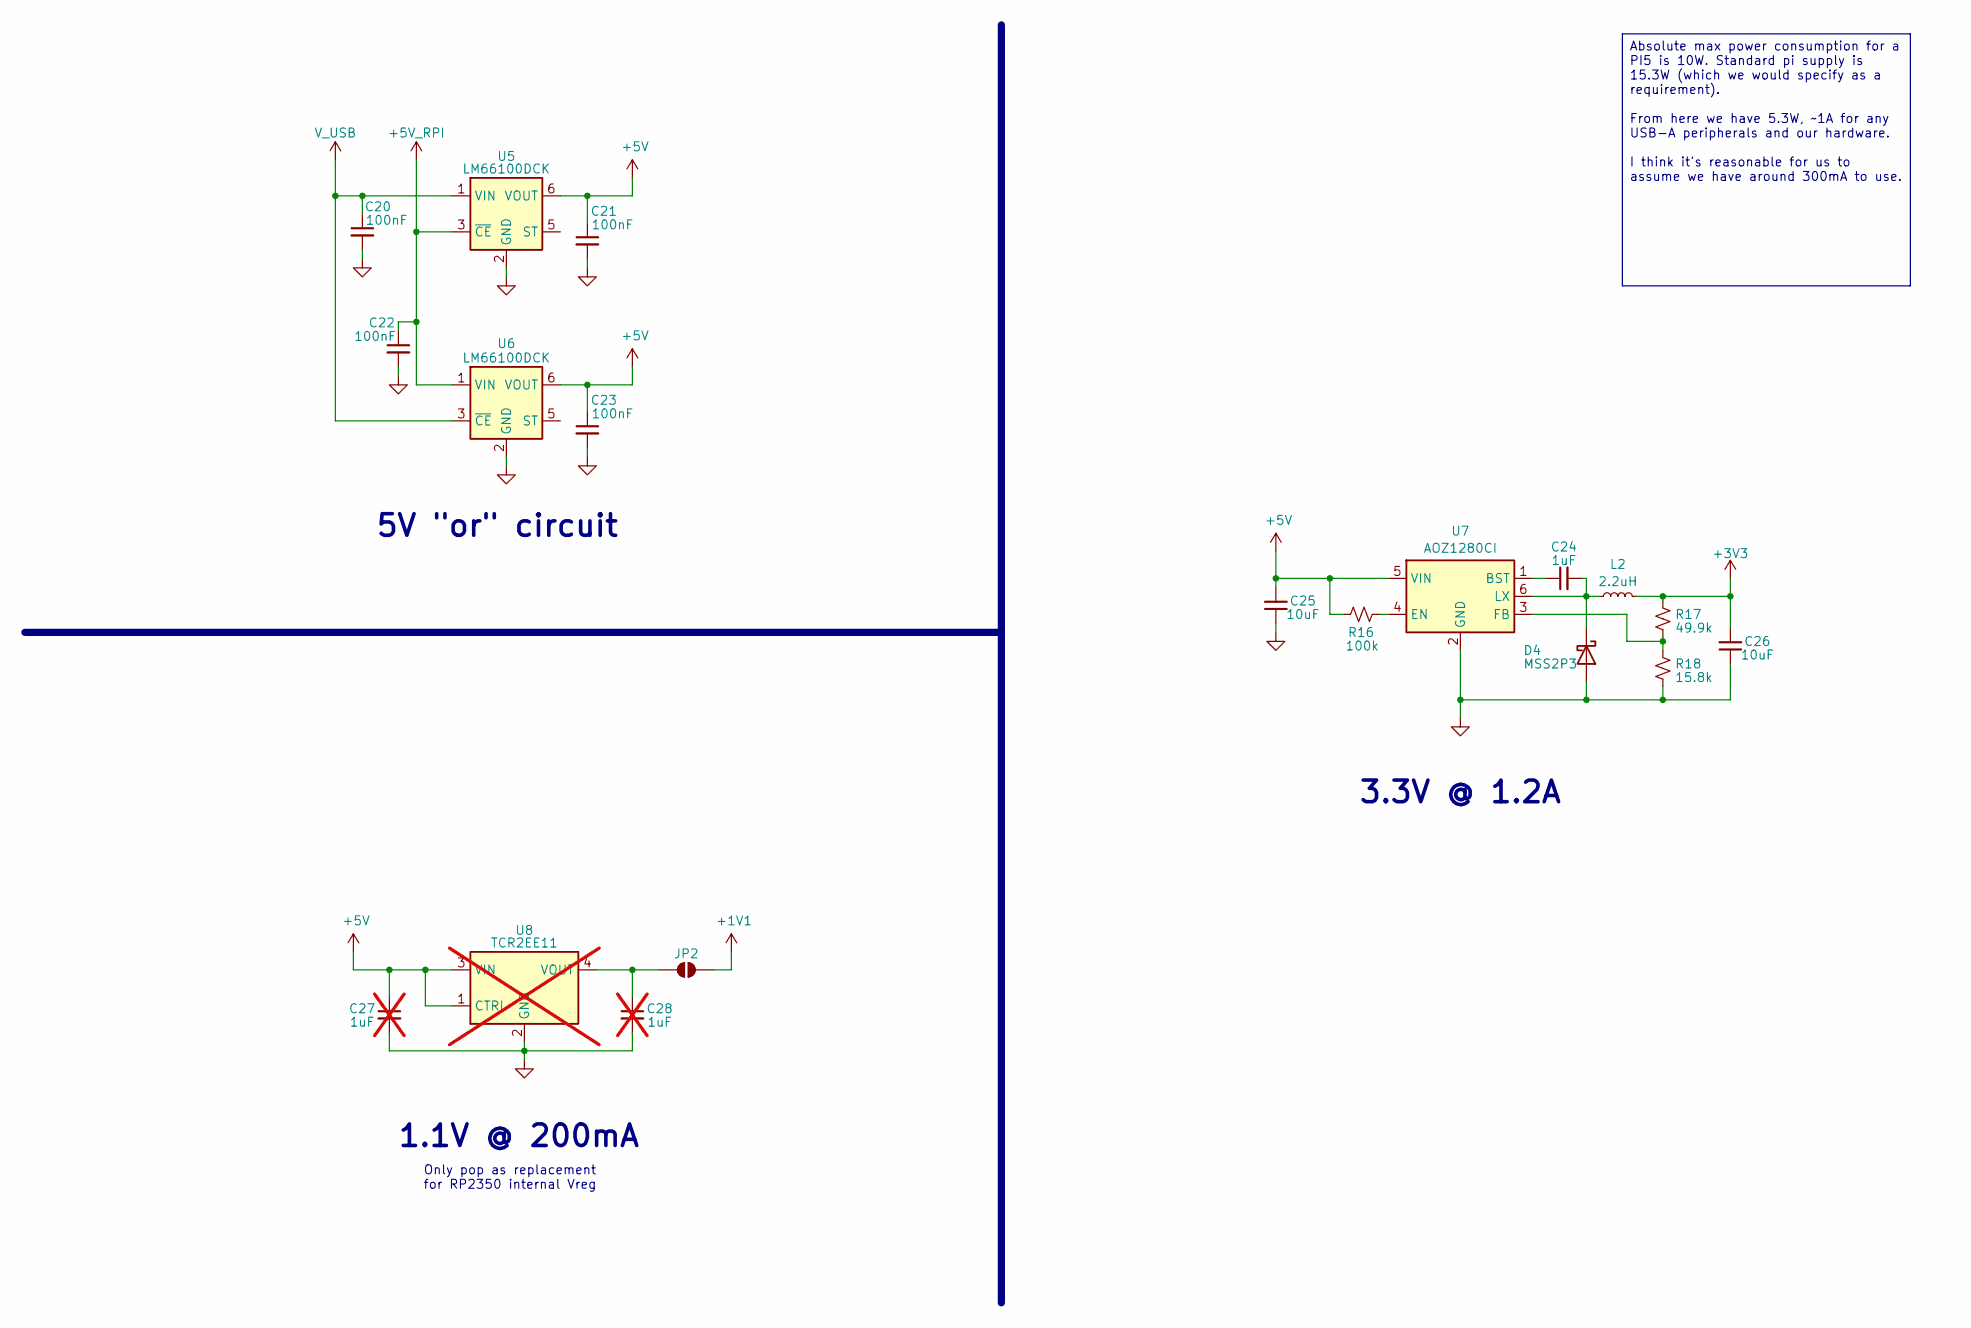
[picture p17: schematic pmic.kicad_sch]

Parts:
C20, C21, C22, C23: 100nF; C_0402_1005Metric; MPN CL05B104KP5NNNC
C24: 1uF; C_0402_1005Metric; MPN JMK105BJ105KV-F
C25, C26: 10uF; C_0603_1608Metric; MPN GRM188R61E106KA73J
C27, C28: 1uF; C_0402_1005Metric; MPN JMK105BJ105KV-F; not fitted
D4: MSS2P3; D_MicroSMP_AK; MPN MSS2P3-M3/89A
JP2: SolderJumper_2_Open; SolderJumper-2_P1.3mm_Open_RoundedPad1.0x1.5mm
L2: 2.2uH; L_1008_2520Metric; MPN DFE252012P-2R2M=P2
R16: 100k; R_0402_1005Metric; MPN RC0402FR-13100KL
R17: 49.9k; R_0402_1005Metric; MPN RC0402FR-1349K9L
R18: 15.8k; R_0402_1005Metric; MPN RC0402FR-1315K8L
U5, U6: LM66100DCK; SOT-363_SC-70-6; MPN LM66100DCKR
U7: AOZ1280CI; SOT-23-6; MPN AOZ1280CI
U8: TCR2EE11; SOT-553; MPN TCR2EE11,LM(CT; not fitted

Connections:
+1V1: JP2.2 (B); also elsewhere on the board
+3V3: C26.2, L2.2, R17.2; also elsewhere on the board
+5V: C21.1, C23.1, C25.2, C27.1, R16.1, U5.6 (VOUT), U6.6 (VOUT), U7.5 (VIN), U8.1 (CTRL), U8.3 (VIN); also elsewhere on the board
+5V_RPI: C22.1, U5.3 (~CE), U6.1 (VIN); also elsewhere on the board
GND: C20.2, C21.2, C22.2, C23.2, C25.1, C26.1, C27.2, C28.2, D4.2 (A), R18.1, U5.2 (GND), U6.2 (GND), U7.2 (GND), U8.2 (GND); also elsewhere on the board
unnamed: C24.2, D4.1 (K), L2.1, U7.6 (LX)
unnamed: C28.1, JP2.1 (A), U8.4 (VOUT)
unnamed: C24.1, U7.1 (BST)
unnamed: R16.2, U7.4 (EN)
unnamed: R17.1, R18.2, U7.3 (FB)
V_USB: C20.1, U5.1 (VIN), U6.3 (~CE); also elsewhere on the board

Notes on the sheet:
1.1V @ 200mA
5V "or" circuit
Only pop as replacement for RP2350 internal Vreg
3.3V @ 1.2A
Absolute max power consumption for a PI5 is 10W. Standard pi supply is 15.3W (which we would specify as a requirement). From here we have 5.3W, ~1A for any USB-A peripherals and our hardware. I think it's reasonable for us to assume we have around 300mA to use.

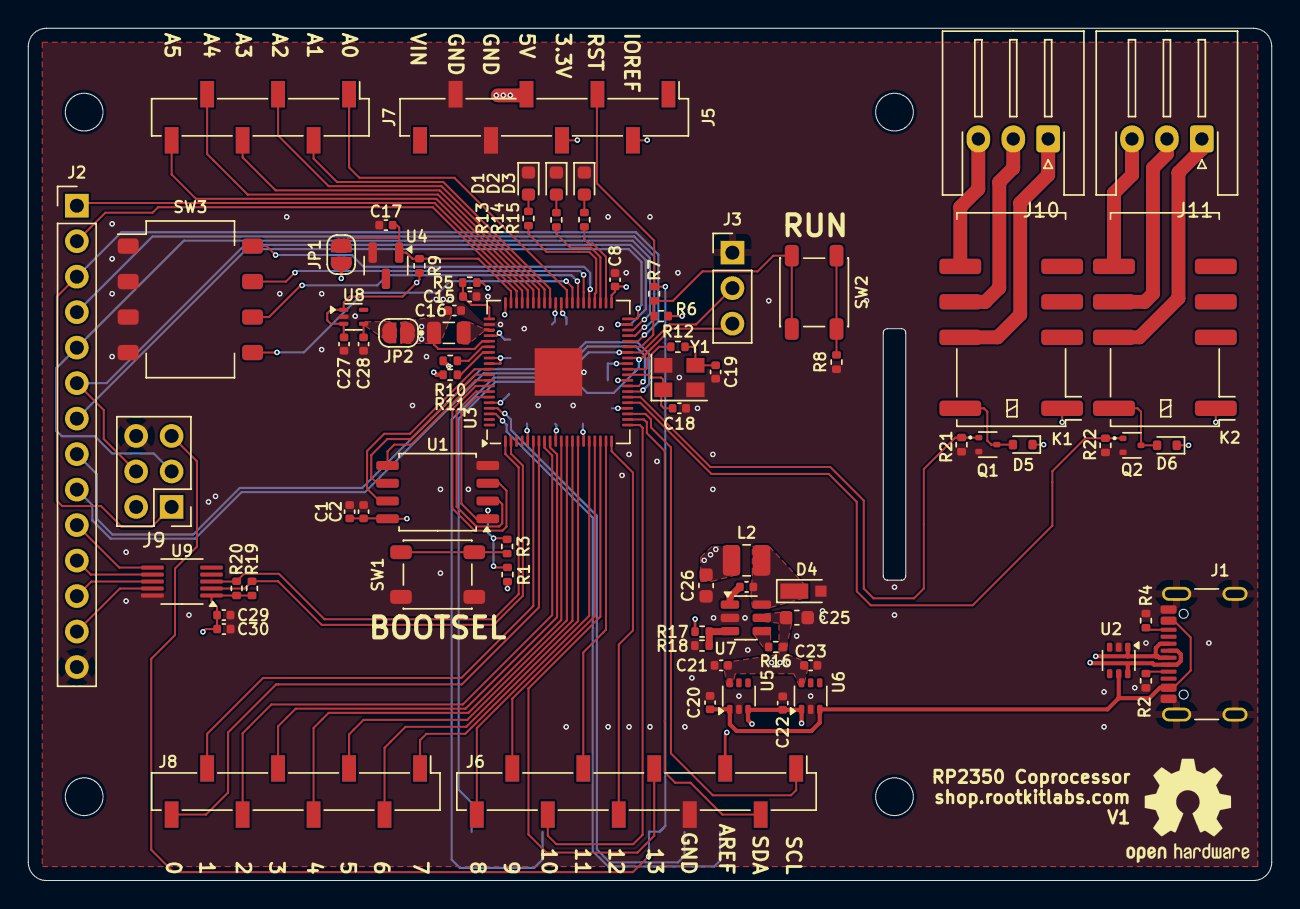
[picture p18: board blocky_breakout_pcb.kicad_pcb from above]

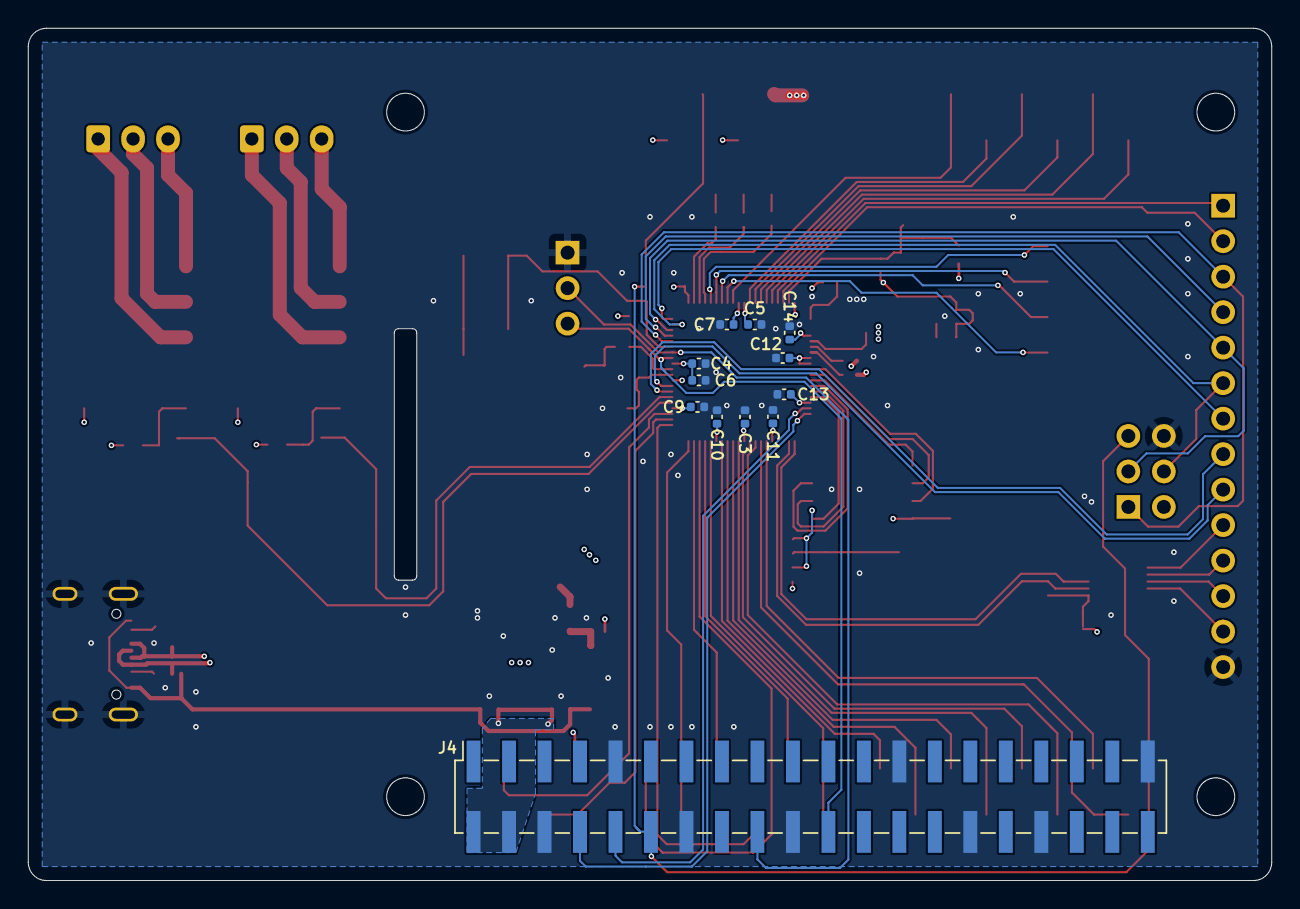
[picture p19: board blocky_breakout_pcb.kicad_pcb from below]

Board: 4 copper layers, 89.0 x 61.0 mm, 94 parts (16 on the bottom side), 95 nets.

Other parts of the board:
K2: EE2-3TNUH; Relay_DPDT_Kemet_EE2_NU

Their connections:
+3V3: K2.1; also elsewhere on the board
unnamed 75: K2.12; also elsewhere on the board
unnamed 81: K2.10; also elsewhere on the board
unnamed 82: K2.9; also elsewhere on the board
unnamed 83: K2.8; also elsewhere on the board

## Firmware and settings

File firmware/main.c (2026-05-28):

#include <ctype.h>
#include <stdio.h>
#include <stdlib.h>
#include <string.h>

#include "hardware/adc.h"
#include "hardware/i2c.h"
#include "hardware/uart.h"
#include "pico/stdlib.h"

#define HOST_UART uart0
#define HOST_BAUD 115200
#define HOST_TX 0
#define HOST_RX 1

#define DAC_I2C i2c0
#define DAC_SDA 4
#define DAC_SCL 5
#define DAC_ADDR 0x60

static const uint8_t digital_gpio[] = {10, 11, 12, 13, 14, 15, 16, 17};
static const uint8_t led_gpio[] = {35, 34, 33};
static const uint8_t switch_gpio[] = {36, 37, 38, 39};
static const uint8_t relay_gpio[] = {24, 25};
static uint16_t dac_raw[] = {0, 0, 0, 0};

static void reply_ok(void) {
    uart_puts(HOST_UART, "OK\n");
}

static void reply_value(uint32_t value) {
    char out[24];
    snprintf(out, sizeof(out), "OK %lu\n", (unsigned long)value);
    uart_puts(HOST_UART, out);
}

static void reply_err(void) {
    uart_puts(HOST_UART, "ERR\n");
}

static bool parse_u32(char **p, uint32_t *value) {
    while (**p == ' ') {
        ++*p;
    }
    if (!isdigit((unsigned char)**p)) {
        return false;
    }
    char *end = NULL;
    unsigned long parsed = strtoul(*p, &end, 10);
    if (end == *p) {
        return false;
    }
    *p = end;
    *value = (uint32_t)parsed;
    return true;
}

static bool valid_index(uint32_t index, size_t count) {
    return index < count;
}

static void dac_write_all(void) {
    uint8_t buf[8];
    for (int ch = 0; ch < 4; ++ch) {
        uint16_t value = dac_raw[ch] & 0x0fff;
        buf[ch * 2] = (uint8_t)(value >> 8);
        buf[ch * 2 + 1] = (uint8_t)value;
    }
    i2c_write_blocking(DAC_I2C, DAC_ADDR, buf, sizeof(buf), false);
}

static void handle_command(char *line) {
    char *p = line;
    while (*p == ' ') {
        ++p;
    }

    if (!strcmp(p, "PING")) {
        uart_puts(HOST_UART, "OK RTSHIELD 1\n");
        return;
    }

    if (!strncmp(p, "AI", 2)) {
        p += 2;
        uint32_t ch;
        if (!parse_u32(&p, &ch) || ch > 7) {
            reply_err();
            return;
        }
        adc_select_input(ch);
        reply_value(adc_read());
        return;
    }

    if (!strncmp(p, "AO", 2)) {
        p += 2;
        uint32_t ch, value;
        if (!parse_u32(&p, &ch) || !parse_u32(&p, &value) || ch > 3 || value > 4095) {
            reply_err();
            return;
        }
        dac_raw[ch] = (uint16_t)value;
        dac_write_all();
        reply_ok();
        return;
    }

    if (!strncmp(p, "DI", 2)) {
        p += 2;
        uint32_t pin;
        if (!parse_u32(&p, &pin) || pin < 2 || pin > 9) {
            reply_err();
            return;
        }
        reply_value(gpio_get(digital_gpio[pin - 2]));
        return;
    }

    if (!strncmp(p, "DO", 2)) {
        p += 2;
        uint32_t pin, value;
        if (!parse_u32(&p, &pin) || !parse_u32(&p, &value) || pin < 2 || pin > 9 || value > 1) {
            reply_err();
            return;
        }
        gpio_set_dir(digital_gpio[pin - 2], GPIO_OUT);
        gpio_put(digital_gpio[pin - 2], value);
        reply_ok();
        return;
    }

    if (!strncmp(p, "DM", 2)) {
        p += 2;
        uint32_t pin, output;
        if (!parse_u32(&p, &pin) || !parse_u32(&p, &output) || pin < 2 || pin > 9 || output > 1) {
            reply_err();
            return;
        }
        gpio_set_dir(digital_gpio[pin - 2], output ? GPIO_OUT : GPIO_IN);
        reply_ok();
        return;
    }

    if (!strncmp(p, "LED", 3)) {
        p += 3;
        uint32_t led, value;
        if (!parse_u32(&p, &led) || !parse_u32(&p, &value) || !valid_index(led, 3) || value > 1) {
            reply_err();
            return;
        }
        gpio_put(led_gpio[led], value);
        reply_ok();
        return;
    }

    if (!strncmp(p, "SW", 2)) {
        p += 2;
        uint32_t sw;
        if (!parse_u32(&p, &sw) || !valid_index(sw, 4)) {
            reply_err();
            return;
        }
        reply_value(!gpio_get(switch_gpio[sw]));
        return;
    }

    if (!strncmp(p, "REL", 3)) {
        p += 3;
        uint32_t relay, value;
        if (!parse_u32(&p, &relay) || !parse_u32(&p, &value) || !valid_index(relay, 2) || value > 1) {
            reply_err();
            return;
        }
        gpio_put(relay_gpio[relay], value);
        reply_ok();
        return;
    }

    reply_err();
}

static void init_io(void) {
    uart_init(HOST_UART, HOST_BAUD);
    gpio_set_function(HOST_TX, GPIO_FUNC_UART);
    gpio_set_function(HOST_RX, GPIO_FUNC_UART);

    adc_init();
    for (uint8_t gpio = 40; gpio <= 47; ++gpio) {
        adc_gpio_init(gpio);
    }

    i2c_init(DAC_I2C, 400000);
    gpio_set_function(DAC_SDA, GPIO_FUNC_I2C);
    gpio_set_function(DAC_SCL, GPIO_FUNC_I2C);
    gpio_pull_up(DAC_SDA);
    gpio_pull_up(DAC_SCL);

    for (size_t i = 0; i < sizeof(digital_gpio); ++i) {
        gpio_init(digital_gpio[i]);
        gpio_set_dir(digital_gpio[i], GPIO_IN);
    }
    for (size_t i = 0; i < sizeof(led_gpio); ++i) {
        gpio_init(led_gpio[i]);
        gpio_set_dir(led_gpio[i], GPIO_OUT);
        gpio_put(led_gpio[i], 0);
    }
    for (size_t i = 0; i < sizeof(switch_gpio); ++i) {
        gpio_init(switch_gpio[i]);
        gpio_set_dir(switch_gpio[i], GPIO_IN);
        gpio_pull_up(switch_gpio[i]);
    }
    for (size_t i = 0; i < sizeof(relay_gpio); ++i) {
        gpio_init(relay_gpio[i]);
        gpio_set_dir(relay_gpio[i], GPIO_OUT);
        gpio_put(relay_gpio[i], 0);
    }
    dac_write_all();
}

int main(void) {
    init_io();

    char line[64];
    size_t len = 0;
    while (true) {
        char c = uart_getc(HOST_UART);
        if (c == '\r') {
            continue;
        }
        if (c == '\n') {
            line[len] = 0;
            handle_command(line);
            len = 0;
            continue;
        }
        if (len + 1 < sizeof(line)) {
            line[len++] = c;
        }
    }
}

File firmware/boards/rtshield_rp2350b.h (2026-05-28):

// RTShield RP2350B board definition for the Raspberry Pi Pico SDK.

#ifndef _BOARDS_RTSHIELD_RP2350B_H
#define _BOARDS_RTSHIELD_RP2350B_H

pico_board_cmake_set(PICO_PLATFORM, rp2350)

#define RTSHIELD_RP2350B
#define PICO_RP2350A 0

#ifndef PICO_DEFAULT_UART
#define PICO_DEFAULT_UART 0
#endif
#ifndef PICO_DEFAULT_UART_TX_PIN
#define PICO_DEFAULT_UART_TX_PIN 0
#endif
#ifndef PICO_DEFAULT_UART_RX_PIN
#define PICO_DEFAULT_UART_RX_PIN 1
#endif

#ifndef PICO_DEFAULT_I2C
#define PICO_DEFAULT_I2C 0
#endif
#ifndef PICO_DEFAULT_I2C_SDA_PIN
#define PICO_DEFAULT_I2C_SDA_PIN 4
#endif
#ifndef PICO_DEFAULT_I2C_SCL_PIN
#define PICO_DEFAULT_I2C_SCL_PIN 5
#endif

#define PICO_BOOT_STAGE2_CHOOSE_W25Q080 1

pico_board_cmake_set_default(PICO_FLASH_SIZE_BYTES, (4 * 1024 * 1024))
#ifndef PICO_FLASH_SIZE_BYTES
#define PICO_FLASH_SIZE_BYTES (4 * 1024 * 1024)
#endif

pico_board_cmake_set_default(PICO_RP2350_A2_SUPPORTED, 1)
#ifndef PICO_RP2350_A2_SUPPORTED
#define PICO_RP2350_A2_SUPPORTED 1
#endif

#endif

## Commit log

2025-08-14 Layout nearly finished, entering part numbers
    [arduino_headers.kicad_sch, blocky_breakout_pcb.kicad_pcb, blocky_breakout_pcb.kicad_sch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]
2025-08-19 Added some docs, worked on routing.
    [blocky_breakout_pcb.kicad_pcb, rp2350.kicad_sch]
2025-08-19 Added gerbers, added 2x3 Arduino header.
    [arduino_headers.kicad_sch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]
2025-08-20 Added remaining part numbers, removed silk for holes, minor touchups
    [arduino_headers.kicad_sch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]
2025-09-02 R0.1 released
    [arduino_headers.kicad_sch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]
2025-09-24 R0.1 updated
    [blocky_breakout_pcb-B_Cu.gbr, blocky_breakout_pcb-B_Fab.gbr, blocky_breakout_pcb-B_Mask.gbr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]
2026-05-28 Made a board specific defn' file, added some more setup instructions in the readme.
